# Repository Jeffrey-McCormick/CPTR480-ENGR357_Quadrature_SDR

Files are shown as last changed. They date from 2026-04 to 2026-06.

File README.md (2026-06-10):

# CPTR480 Quadrature SDR Hardware Documentation

This repository contains the KiCad schematics, PCB layouts, and Bills of Materials for the CPTR480 Quadrature Software Defined Radio (SDR) receiver board designed by Jeffrey McCormick and Daniel Mendoza for ENGR357 and CPTR480.

**Other contributors**: Riley Smith, Joshua Garbi

## System Architecture

The radio is a direct-conversion, quadrature-sampling receiver (commonly utilizing a Tayloe Detector topology) managed by a Raspberry Pi Pico. The RF front-end downconverts the incoming antenna signal directly to baseband I (In-phase) and Q (Quadrature) audio signals, which are digitized and processed by the RP2040 microcontroller. The board also includes other parts like rotary encoder, OLED display, SD card reader, and DAC for audio output for added functionality. The radio is designed work both on battery power as well as USB power through the Raspberry Pi Pico. The board is designed to be portable and hand-held. 

### Core Hardware Modules

1. **Microcontroller & Digital Core**
   - **Raspberry Pi Pico (RP2040)**: The brains of the SDR. Handles I2C UI/Hardware control, I2S digital audio streams, DSP, and SD card interfacing. The board will support both the original Raspberry Pi Pico board varients and the YD2040 from CPTR480. 

2. **RF Front-End & Mixing (Tayloe Detector)**
   - **SN74CBT3253CDBR**: Dual 1-of-4 FET Multiplexer/Demultiplexer. This high-speed analog switch acts as the quadrature mixer, sequentially sampling the incoming RF signal at the Local Oscillator frequency to produce differential baseband I and Q signals. A second SN74CBT was used for RF filter switching in the front-end.   
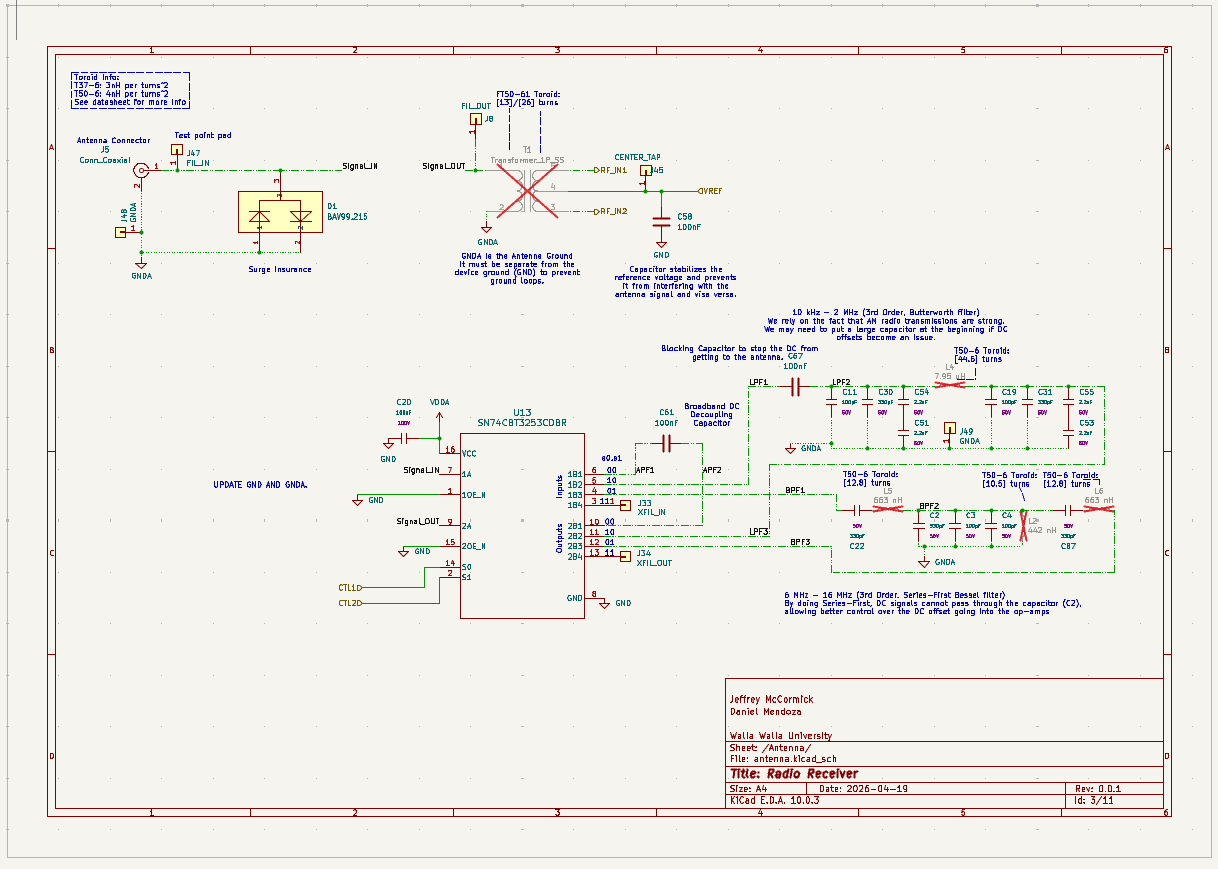
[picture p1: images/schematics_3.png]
SN74CBT3253CDBR
   
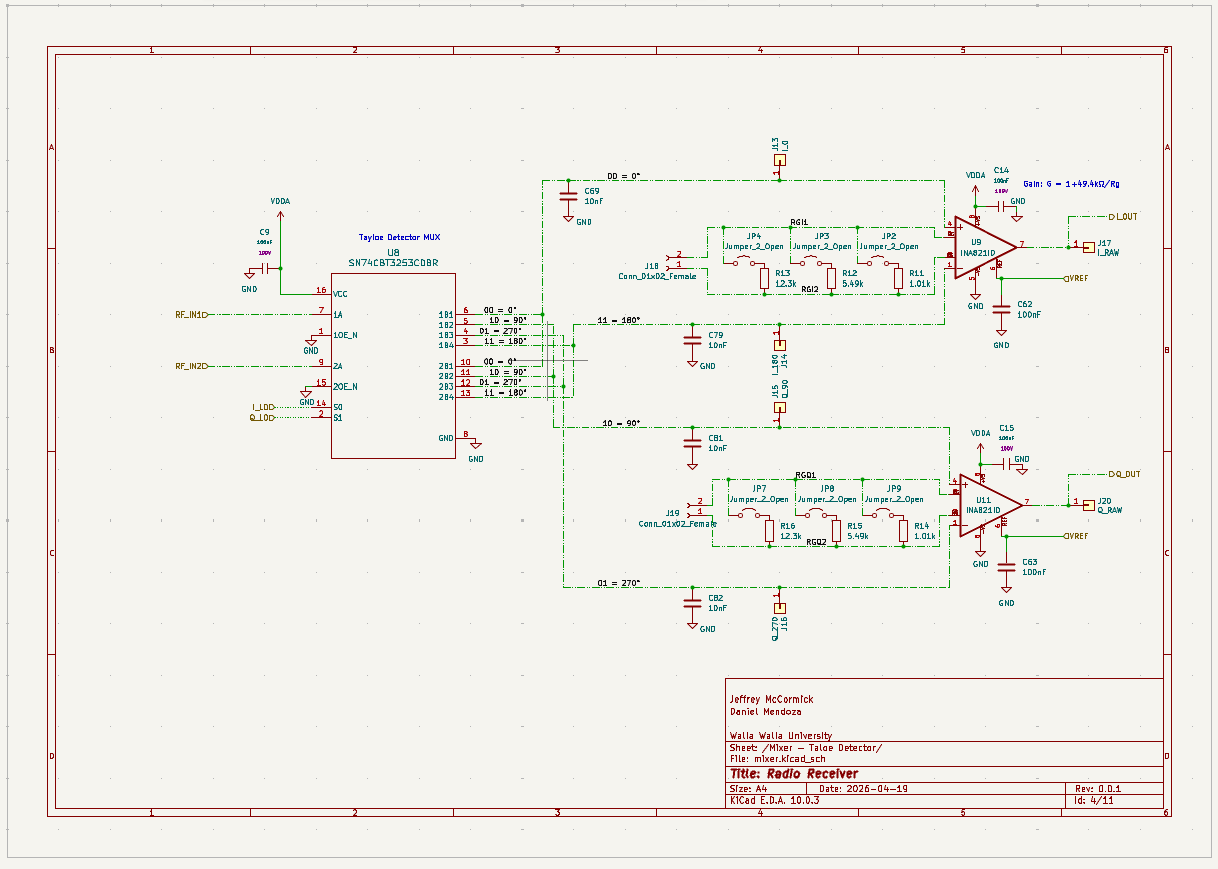
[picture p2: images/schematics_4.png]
Tayloe Detector
   
   - **SN74AC74DR**: Dual D-Type Positive-Edge-Triggered Flip-Flop, typically used to accurately divide the synthesized clock to drive the Tayloe detector switches with precise 90-degree phase offsets.
   Johnson Counter
   
3. **Clock Generation**
   - **Si5351A-B-GT**: I2C-programmable ANY-frequency CMOS clock generator. Driven by a high-precision **24.576 MHz TCXO** (ASTX-H11) for ultra-low drift, it synthesizes the Local Oscillator (LO) frequencies. For quadrature mixing, it is configured to output signals at 4x the target listen frequency.
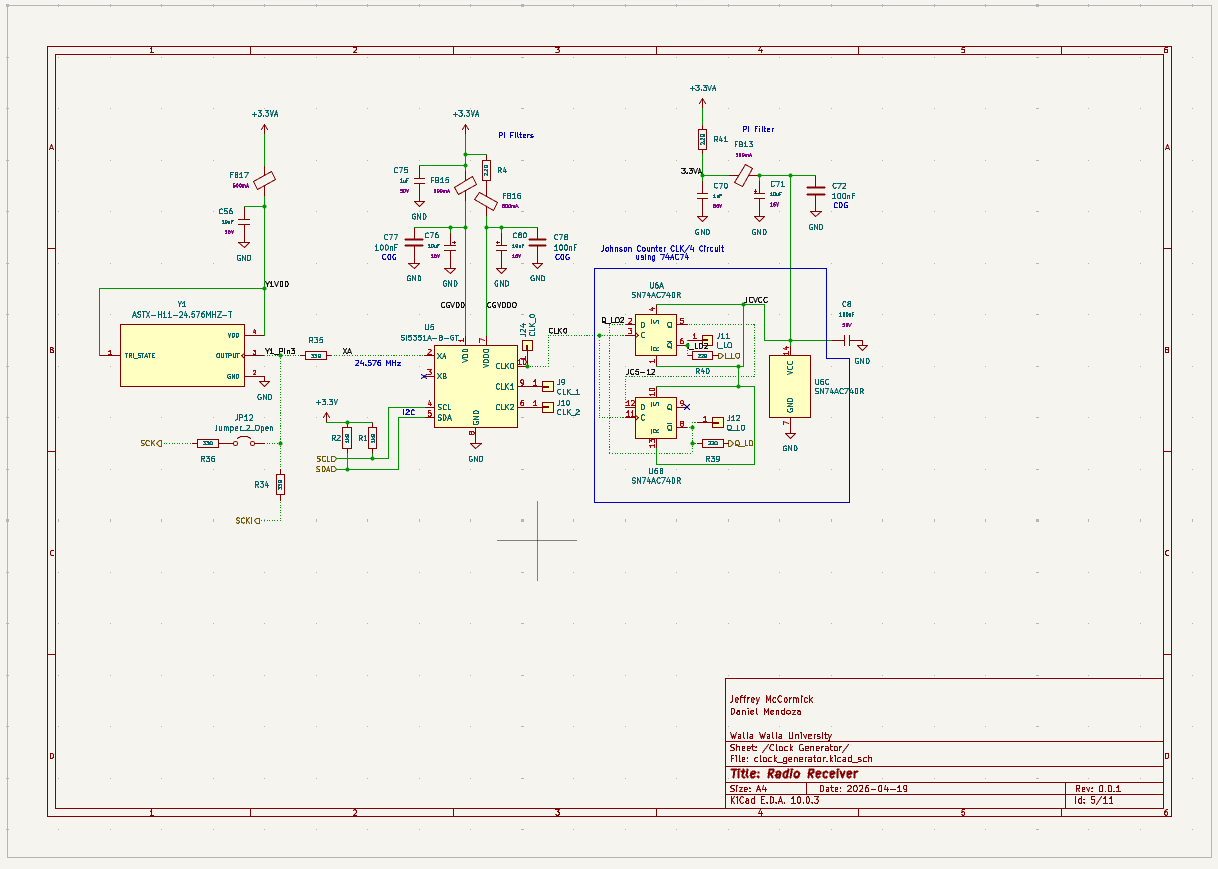
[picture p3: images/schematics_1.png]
Si5351A-B-GT
   

4. **Baseband Amplification**
   - **INA821ID**: High-precision instrumentation amplifiers used to convert the differential outputs of the Tayloe mixer to single-ended signals and apply initial low-noise gain.
   - **OPA1612AxD**: Dual SoundPlus™ high-performance bipolar-input audio operational amplifiers for active low-pass filtering and final baseband gain stages.

5. **Data Converters (Audio/Baseband)**
   - **PCM1808PWR**: 24-bit, 96-kHz Stereo ADC. Digitizes the analog I and Q baseband signals and sends them to the Pico over I2S.
   - **PCM5102A**: 32-bit, 384-kHz Stereo DAC with integrated PLL. Converts the final DSP-processed audio or playback audio from the Pico back to analog for the headphone output.
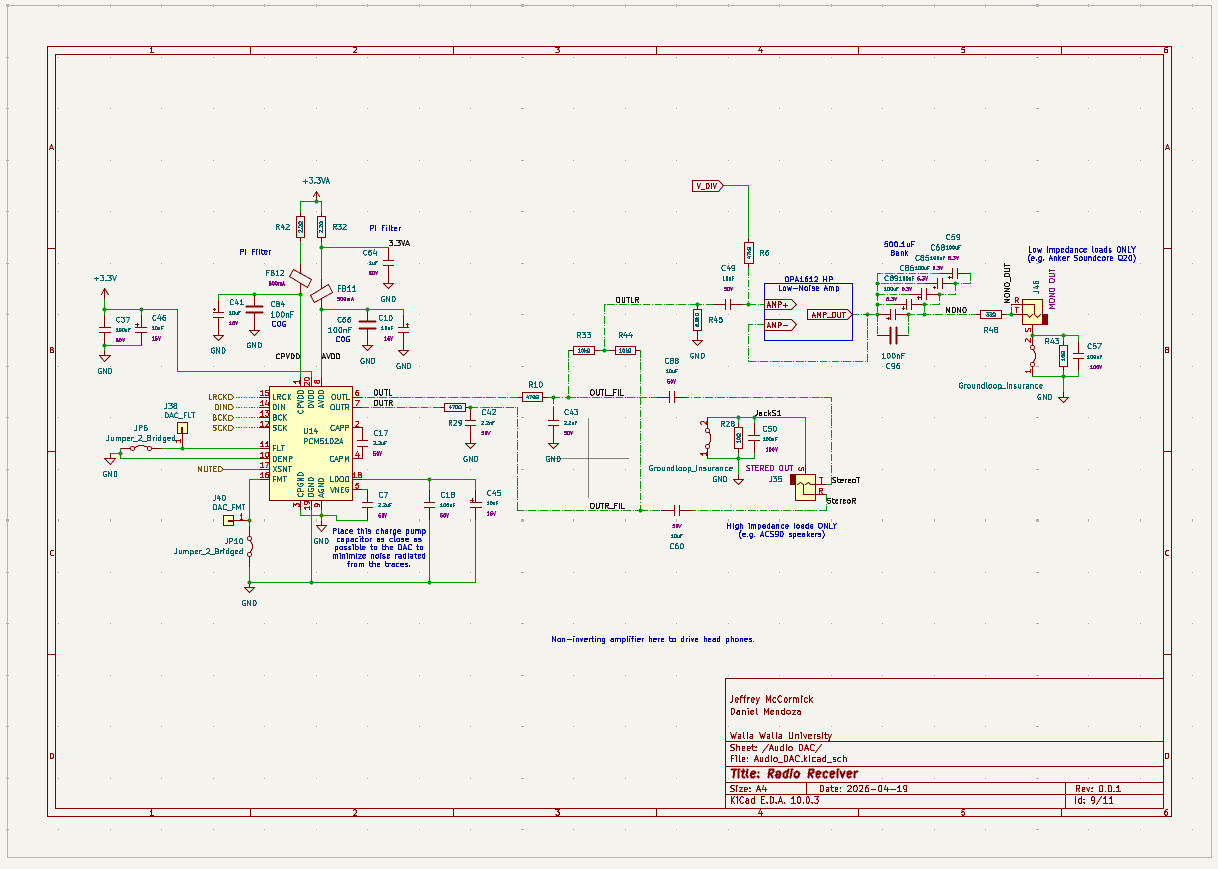
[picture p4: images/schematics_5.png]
DAC
   

6. **User Interface**
   - **0.96" OLED Display**: 128x64 pixels, I2C interface.
   - **Rotary Encoder (Alps EC11)**: Includes a push-button switch for frequency tuning and menu navigation.
   - **Tactile Button**: For additional UI control inputs.

7. **Power Management**
   - **TPS7A2045PDQN**: 4.5V Ultra-Low-Noise LDO regulator for sensitive analog components.
   - **TPS72733DSER**: 3.3V Low-Dropout regulator for clean digital/mixed-signal voltage rails.
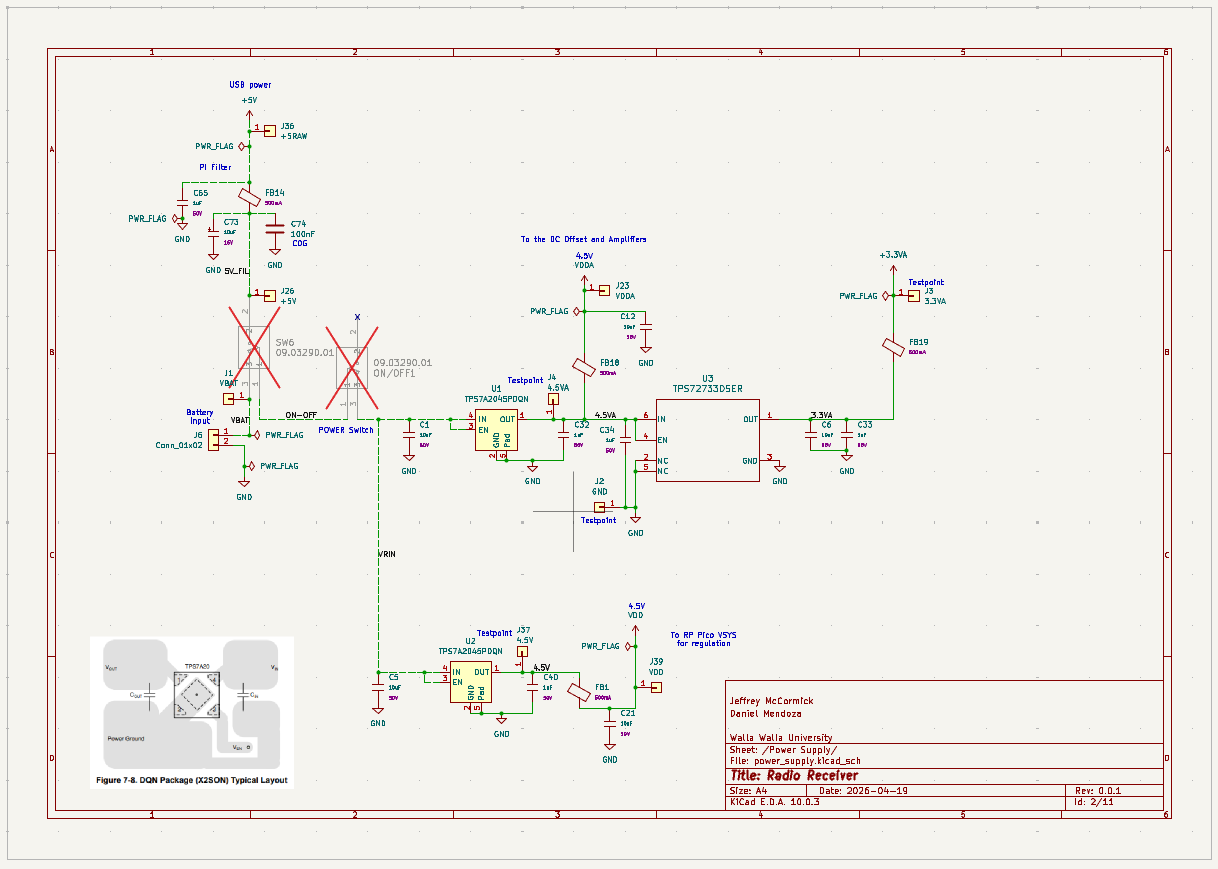
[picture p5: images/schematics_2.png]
Power Management
   

8. **Connectivity**
   - **BNC Connector (Amphenol)**: Main RF antenna input.
   - **3.5mm Audio Jacks (CUI SJ-3523-SMT)**: For SDR audio output and DAC direct output.
   - **MicroSD Card Slot**: Connected via SPI for playing WAV files or potentially recording IQ streams.

## KiCad Project Structure

The hardware source files are located in the `Radio_Receiver_McCormick_Mendoza` directory. The schematic is built hierarchically:

- **`Radio_Receiver_McCormick_Mendoza.kicad_sch`**: The top-level schematic tying all functional blocks together.
- **`antenna.kicad_sch` / `low_pass_filter.kicad_sch`**: Front-end filtering blocks.
- **`mixer.kicad_sch`**: The Tayloe detector and RF switching core.
- **`clock_generator.kicad_sch`**: Si5351 synthesizer and TCXO.
- **`ADC-24bit.kicad_sch` / `Audio_DAC.kicad_sch`**: Data converter sub-sheets.
- **`raspberry_pi_pico.kicad_sch`**: MCU pinning and decoupling.
- **`power_supply.kicad_sch`**: LDOs and power distribution network.
- **`Display.kicad_sch` / `Angle_Encoder.kicad_sch`**: UI peripherals.

### PCB Images
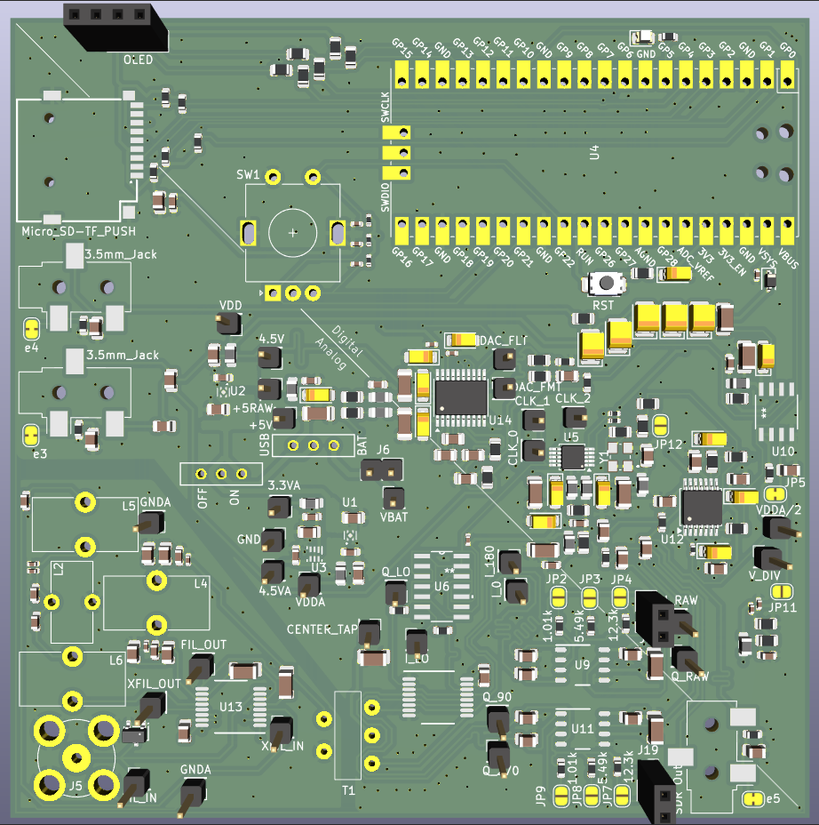
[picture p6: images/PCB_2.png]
Front of Board

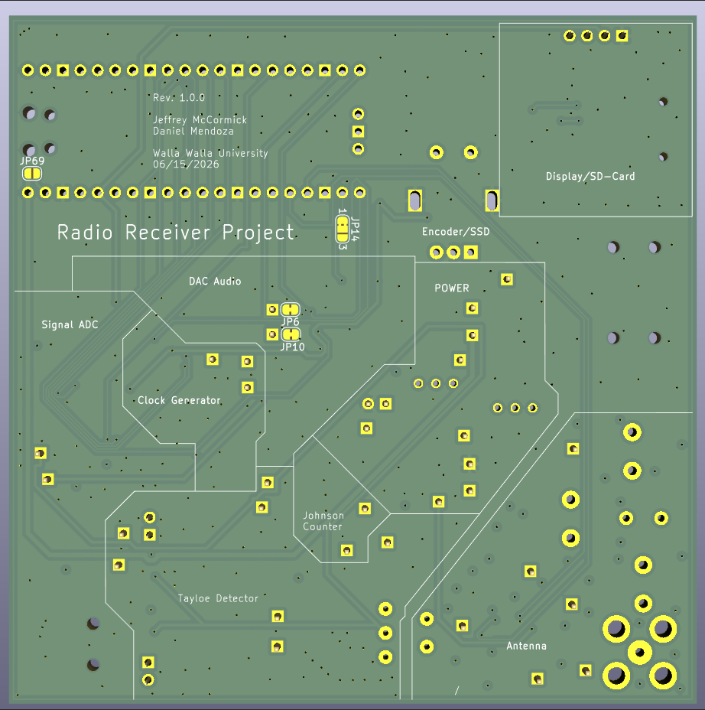
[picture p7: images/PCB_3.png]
Back of Board

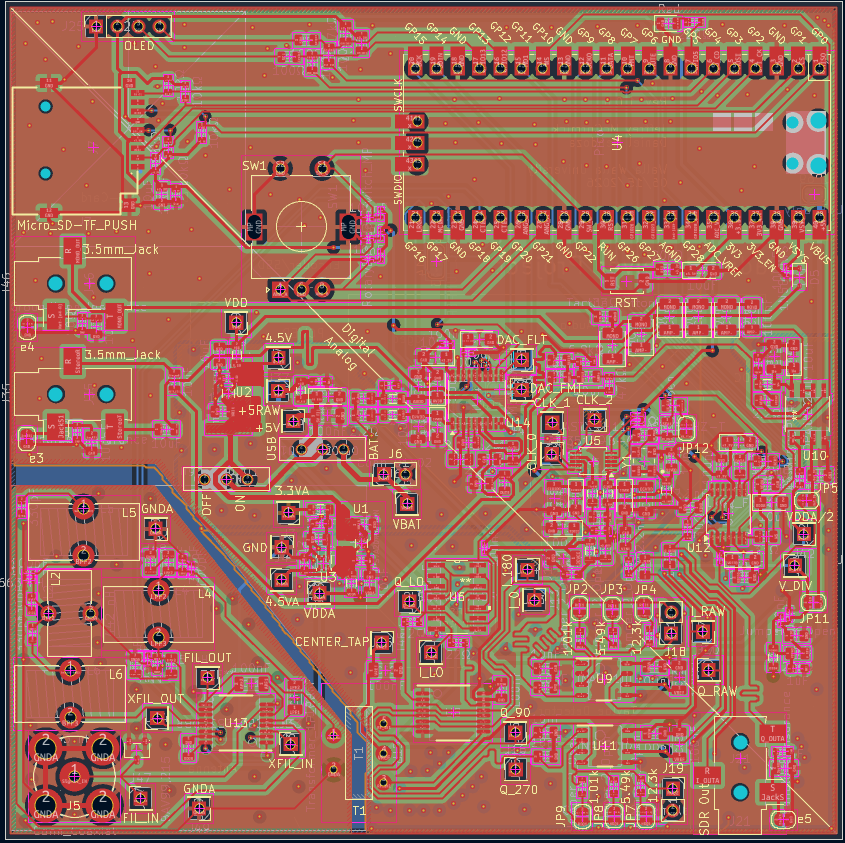
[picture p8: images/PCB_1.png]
PCB


### Bill of Materials (BOM)

The complete component list, including LCSC part numbers for JLCPCB assembly, can be found in `Radio_Receiver_McCormick_Mendoza.csv`.

## Bring-up and Testing Order

Standalone scripts used during hardware validation. Each can be uploaded and run independently on the board.

| Component | File | Function | Pass/Fail |
|---|---|---|---|
| LED | `Bringup/led_blink.py` | Blinks GPIO5 to confirm basic GPIO and upload toolchain | &check; |
| I2C bus | `Bringup/i2c_scan.py` | Scans I2C0 (SDA=12, SCL=13); expects Si5351 at `0x60`, OLED at `0x3C` | &check; |
| OLED display | `Bringup/oled_test.py` | Full exercise suite for the SSD1306 (text, lines, animation, contrast, power cycle) via `ssd1306.py` | &check; |
| Rotary encoder + button | `Bringup/rotary_encoder.py` | `QuadratureEncoder` (detent counting on GPIO 20/21) and `ButtonHandler` (debounced click + long-press on GPIO 22) | &check; |
| Si5351 clock | `Bringup/si5351_test.py` | Register R/W test, PLL lock check, 10.24 MHz quadrature setup, frequency sweep with integer-divider validation | &check; |
| Filter MUX | `Bringup/filter_mux_control.py` | Drives CTL1 (GPIO19) and CTL2 (GPIO18) to select one of four analog filter paths | &check; |
| Si5351 driver | `Bringup/Load_files/si5351.py` | I2C driver: PLL/multiplier config, per-clock dividers, phase offset, output enable | &check; |
| OLED driver | `Bringup/Load_files/ssd1306.py` | Standard MicroPython SSD1306 I2C framebuffer driver | &check; |
| DAC | `Bringup/dac.py` | I2S driver: Configure DAC for stereo or mono playback at 44.1 kHz | &check; |
| ADC | `Bringup/adc.py` | I2S driver: Configure ADC for 16-bit stereo sampling | &cross; |
|  ADC Integration | `Bringup/adc_test.py` | Full duplex loopback test: DAC outputs a sine wave, ADC reads it back, and an LED toggles based on amplitude | &cross; |

**`si5351_test.py` details:** Configures PLLA with N=25 (VCO = 24.576 MHz × 25 = 614.4 MHz), sets CLK0/1/2 dividers, and applies phase offsets of 0°, 90°, and 180° via `set_phase()`. The `is_integer_divider()` helper ensures only frequencies that divide the VCO evenly are programmed during the sweep.

**`rotary_encoder.py` details:** Encoder uses IRQ-driven quadrature decoding with detent aggregation (`ppr` parameter). `ButtonHandler` distinguishes short click (on release before 600 ms) from long press (held ≥ 600 ms); the main app uses long press for "back" navigation.
### Images
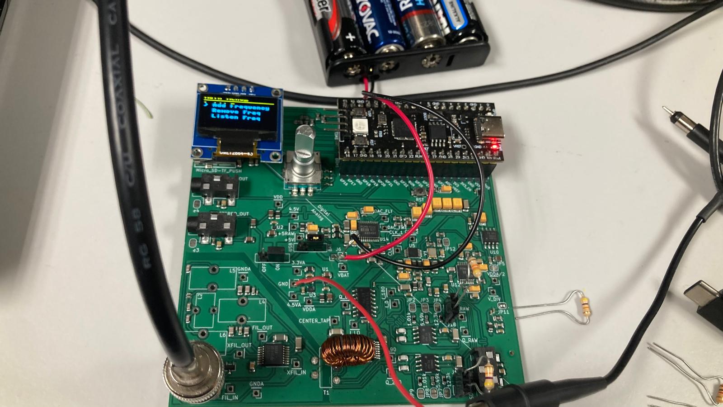
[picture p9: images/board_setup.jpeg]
Board Bring-UP


## Results

Base Goals

- [x]  Minimum Discernable signal less than 1uV
  - Achieved 1mV
- [ ]  Switching between AM and HF bands
  - Only tested for AM band. 
- [x]  Intuitive interface
  - Got it. See /Software 
- [x]  Portability
   - Battery power works well. Antenna and Board grounds have to be tied together for portable antenna grounding
- [x]  Dual power mode (battery and usb)
   - Got it!! Both work as intended.

 Reach Goals:

- [x]  Low noise (-60dB)
  - Achieved -90dB
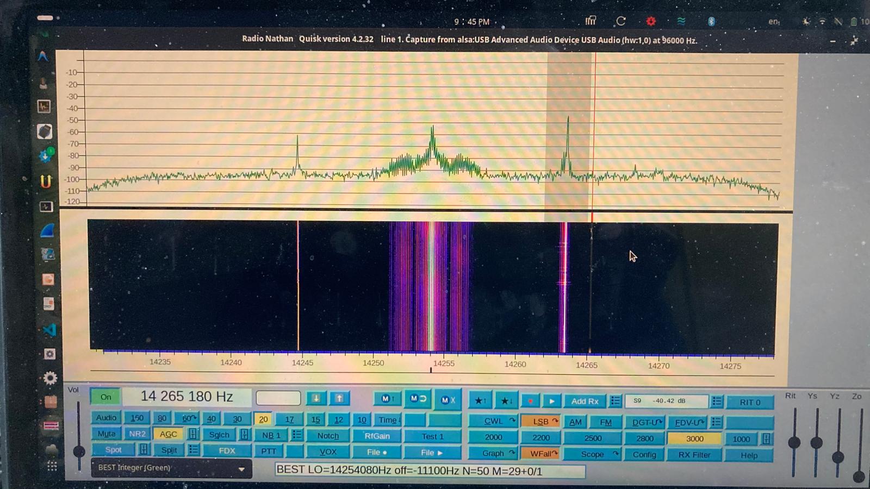
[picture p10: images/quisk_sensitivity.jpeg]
Quisk
  
- [/]  High Image Rejection (-20dB)
- Achieved -15dB to -25dB depending on individual resistor pairs. 
- [ ]  Can record radio signals
   - Unable to test 

### Images
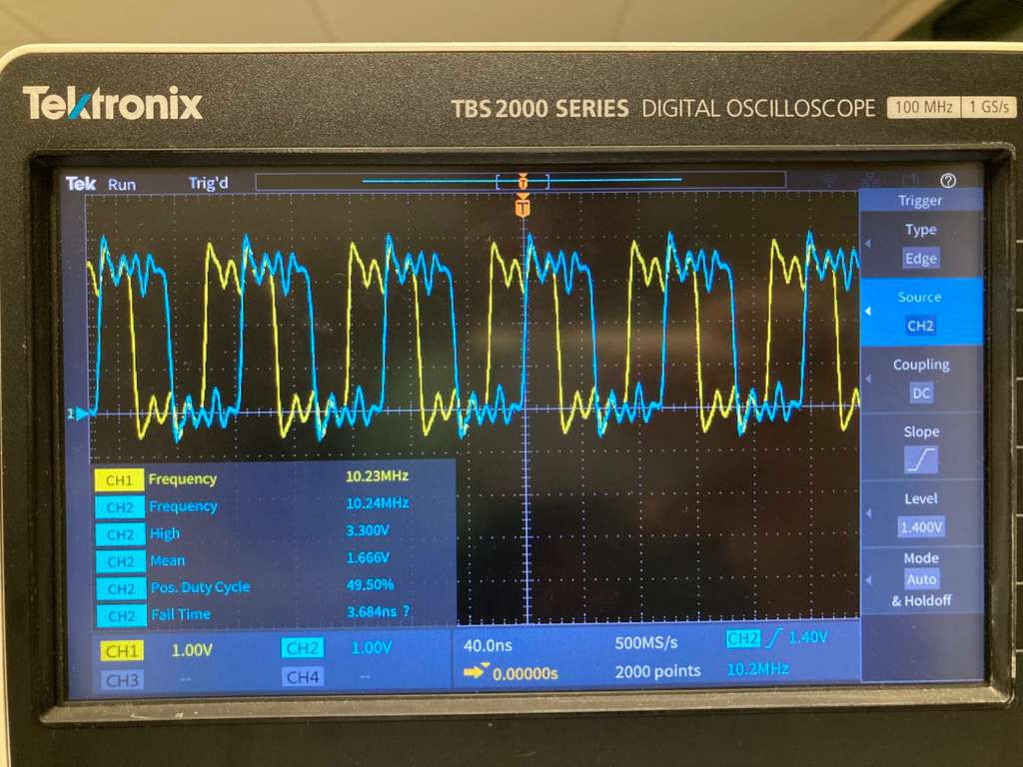
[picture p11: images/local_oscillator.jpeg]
Local Oscillator


## Future Work

- [ ] Input I and Q signls into pico via ADC 
   - ADC verification 
- [ ] Tracelength matching for Q_LO and I_LO
- [ ] Manufacture optional LP and BP Filters
- [ ] RF signal processing software

### Optional
- [ ] Adding option for lower gain in Intrumentation Amplifier.

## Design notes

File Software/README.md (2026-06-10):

# Overview

MicroPython firmware for the CPTR480 Quadrature SDR board (RP2040 / Pico-class). The software drives the Si5351 clock generator for quadrature LO signals, an SSD1306 OLED and rotary encoder for the user interface, an analog filter MUX, and (separately) SD-card WAV playback through a PCM5102A DAC over I2S.

**Entry point:** `main.py` configures the Si5351, then launches the `SDRApp` menu.

**Typical pin map (shared across modules):**

| Signal | GPIO |
|---|---|
| I2C SDA | 12 |
| I2C SCL | 13 |
| Encoder A / B | 20 / 21 |
| Encoder button | 22 |
| DAC I2S BCK / WS / DATA | 15 / 16 / 14 |
| DAC mute (XSMT) | 6 |
| SD SPI CS / SCK / MOSI / MISO | 1 / 2 / 3 / 0 |
| Filter MUX CTL1 / CTL2 | 19 / 18 |

Library copies of `si5351.py` and `ssd1306.py` live in `Bringup/Load_files/` and are imported from there during bringup; production code expects them on the device root alongside the app modules.

---

## Drivers

### Bringup

Standalone scripts used during hardware validation. Each can be uploaded and run independently on the board.

| Component | File | Function | Pass/Fail |
|---|---|---|---|
| LED | `Bringup/led_blink.py` | Blinks GPIO5 to confirm basic GPIO and upload toolchain | — |
| I2C bus | `Bringup/i2c_scan.py` | Scans I2C0 (SDA=12, SCL=13); expects Si5351 at `0x60`, OLED at `0x3C` | — |
| OLED display | `Bringup/oled_test.py` | Full exercise suite for the SSD1306 (text, lines, animation, contrast, power cycle) via `ssd1306.py` | — |
| Rotary encoder + button | `Bringup/rotary_encoder.py` | `QuadratureEncoder` (detent counting on GPIO 20/21) and `ButtonHandler` (debounced click + long-press on GPIO 22) | — |
| Si5351 clock | `Bringup/si5351_test.py` | Register R/W test, PLL lock check, 10.24 MHz quadrature setup, frequency sweep with integer-divider validation | — |
| Filter MUX | `Bringup/filter_mux_control.py` | Drives CTL1 (GPIO19) and CTL2 (GPIO18) to select one of four analog filter paths | — |
| Si5351 driver | `Bringup/Load_files/si5351.py` | I2C driver: PLL/multiplier config, per-clock dividers, phase offset, output enable | — |
| OLED driver | `Bringup/Load_files/ssd1306.py` | Standard MicroPython SSD1306 I2C framebuffer driver | — |

**`si5351_test.py` details:** Configures PLLA with N=25 (VCO = 24.576 MHz × 25 = 614.4 MHz), sets CLK0/1/2 dividers, and applies phase offsets of 0°, 90°, and 180° via `set_phase()`. The `is_integer_divider()` helper ensures only frequencies that divide the VCO evenly are programmed during the sweep.

**`rotary_encoder.py` details:** Encoder uses IRQ-driven quadrature decoding with detent aggregation (`ppr` parameter). `ButtonHandler` distinguishes short click (on release before 600 ms) from long press (held ≥ 600 ms); the main app uses long press for "back" navigation.

---

### UI

The menu system is split between a legacy `Menu` renderer and a page-stack navigation layer.

| File | Role |
|---|---|
| `menu.py` | **`Menu`** — draws a scrollable option list on the 128×64 OLED. **`SDRApp`** — wires I2C/OLED, encoder, and button; owns the frequency list and `NavStack`; main event loop running cooperatively via `asyncio`. |
| `ui/page.py` | **`Page`** base class (`on_enter`, `on_exit`, `handle_input`, `draw`). **`NavStack`** — push/pop/replace for nested screens; root page cannot be popped. |
| `ui/menu_page.py` | **`MenuPage`** — builds a `Menu` from `MenuItem` definitions; click navigates to a child page or runs an action; optional back row. |
| `ui/freq_pages.py` | **`ValueEditorPage`** — encoder adjusts a numeric value in Hz; click saves. **`AddFreqPage`** — adds a frequency to the sorted `app.freqs` list. **`FreqListPage`** — lists saved frequencies for remove or listen actions. |
| `ui/music_pages.py` | **`MusicListPage`** — selectable list of WAV files from the SD card. **`PlaybackPage`** — playback controls (Play, Pause, Exit) for a track, interfacing with `PlaybackController`. |
| `ui/screen_mode_page.py` | **`ScreenModePage`** — placeholder page for displaying SD card photos (Coming Soon). |

**Navigation model:**

- Rotate encoder → move selection up/down.
- Short click → confirm / enter submenu.
- Long press → go back (when not on root menu).

**Main menu options (FrohnePod):**

1. **Radio** — enter submenu to Add, Remove, or Listen to SDR frequencies.
2. **Music Player** — browse `.wav` files on the SD card and enter the playback screen.
3. **Screen Mode** — enter submenu for screen viewing modes.

`main.py` calls `configure_si5351()` before starting the app, setting CLK0 to 1.42 MHz as the initial LO.

---

### Audio Stream

WAV playback from the SD card is handled cooperatively with `asyncio` (not a second RP2040 core). The design keeps the I2S feed non-blocking relative to other tasks by yielding whenever the hardware ring buffer is full.

| File | Role |
|---|---|
| `sd.py` | SPI mount helper (`mount_sd`) and `list_wav_files` for `.wav` files on `/sd`. |
| `sdcard.py` | Low-level SPI SD-card driver (`readblocks` / `writeblocks` for `os.mount`). Busy-poll read path tuned for streaming throughput. |
| `player/PlaybackController.py` | Async WAV streamer: mounts SD, opens PCM5102A via `DAC`, spawns `_stream_task` on `play()`. |

**`PlaybackController` flow:**

1. `initialize()` — mount SD, create `DAC` in non-blocking stereo mode (muted).
2. `play(filename)` — skip WAV header to PCM `data` chunk, start asyncio task.
3. `_stream_task` — reads chunks from the file, writes to I2S directly via non-blocking `write()`, and yields to the UI event loop via `asyncio.sleep_ms(10)` when the hardware ring buffer is full. Unmutes after two buffered chunks; on EOF waits 300 ms for the ring to drain before muting.
4. `pause()` / `resume()` / `stop()` — mute control and task cancellation with a generation counter so stale tasks cannot clobber state.

**Expected audio format:** 16-bit stereo PCM WAV at the DAC sample rate (default 44.1 kHz). Mono or other formats are not handled.

**Standalone usage:** `sd.py` can be run directly (`python sd.py` on-device) to play the first track found on the card.

Watch this lol

---

### DAC

`dac.py` wraps the RP2040 I2S peripheral for a PCM5102A DAC.

| Feature | Detail |
|---|---|
| Pins | BCK=15, WS=16, DATA=14, XSMT mute=6, MCLK=17 |
| Modes | Stereo (default) or mono via `set_stereo()` / `set_mono()` |
| Blocking vs non-blocking | `nonblocking=True` enables non-blocking writes and lets the `PlaybackController` cooperatively yield while the buffer is full |
| Mute | `mute()` / `unmute()` drive XSMT LOW/HIGH |
| Shutdown | `close()` — clears IRQ, mutes, deinits I2S |

The DAC requires an external Master Clock (`MCLK`). `dac.py` sets up a PWM signal on Pin 17 at `256 * sample_rate` to satisfy the PCM5102A's MCLK requirement.

The `__main__` block generates a 440 Hz sine wave for a quick hardware smoke test.

---

## Outcome

### Problems

- **Listen Freq is a stub** — selecting a frequency in `FreqListPage` only prints to the serial console; it does not yet call `Si5351` to retune the LO or select a filter MUX channel.
- **Si5351 config split** — clock setup lives in `main.py` (`configure_si5351`) while the UI frequency list is separate; there is no shared tuning API yet.
- **Module path** — `menu.py` falls back to `Bringup/` on import error; deployed firmware should copy `si5351.py`, `ssd1306.py`, and `rotary_encoder.py` to the device root to avoid path hacks.
- **Encoder debug prints** — `QuadratureEncoder.on_change` still prints on every edge; noisy during normal UI use.
- **WAV assumptions** — playback expects 16-bit stereo PCM; no sample-rate negotiation or resampling.
- **Filter MUX unused in app** — `filter_mux_control.py` is bringup-only; channel selection is not tied to frequency or listen mode.

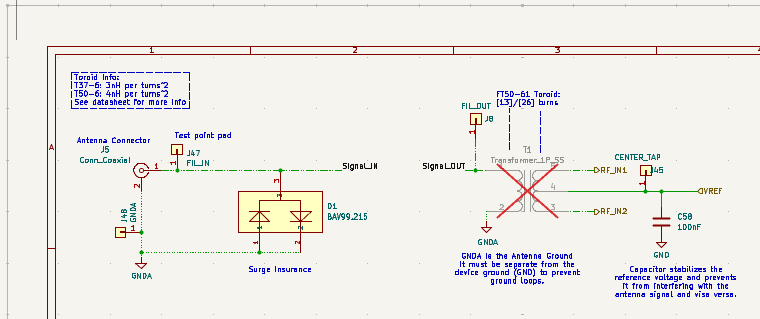
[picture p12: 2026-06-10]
images/schematics_6.png

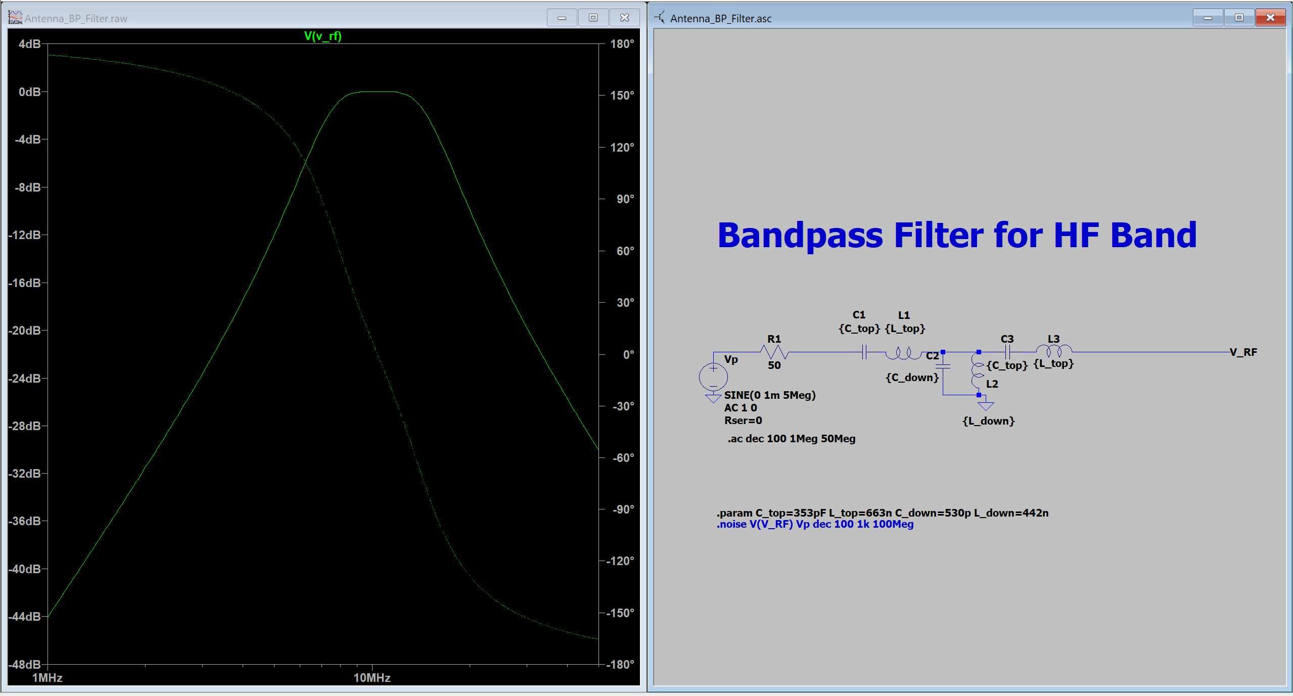
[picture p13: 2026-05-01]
Pictures/BandpassFilterSimulations.png

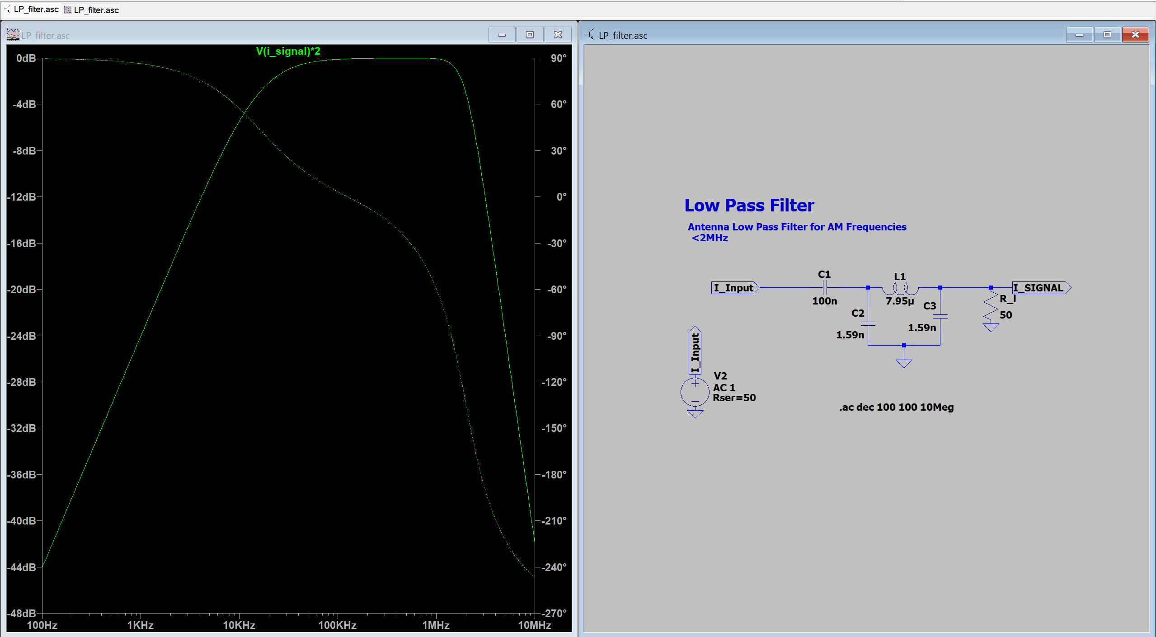
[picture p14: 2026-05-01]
Pictures/LowpassFilterSimulations.png

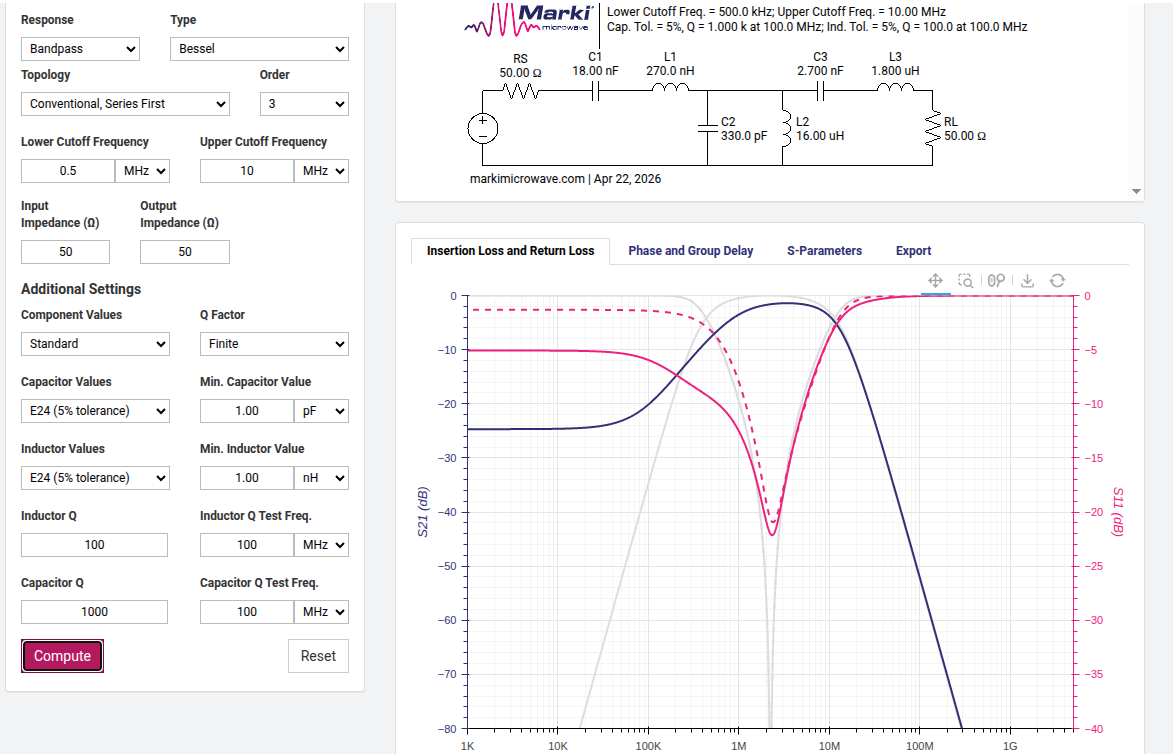
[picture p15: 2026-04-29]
Pictures/MarkiMicrowave_BPF_3rdBessel_Calc.png

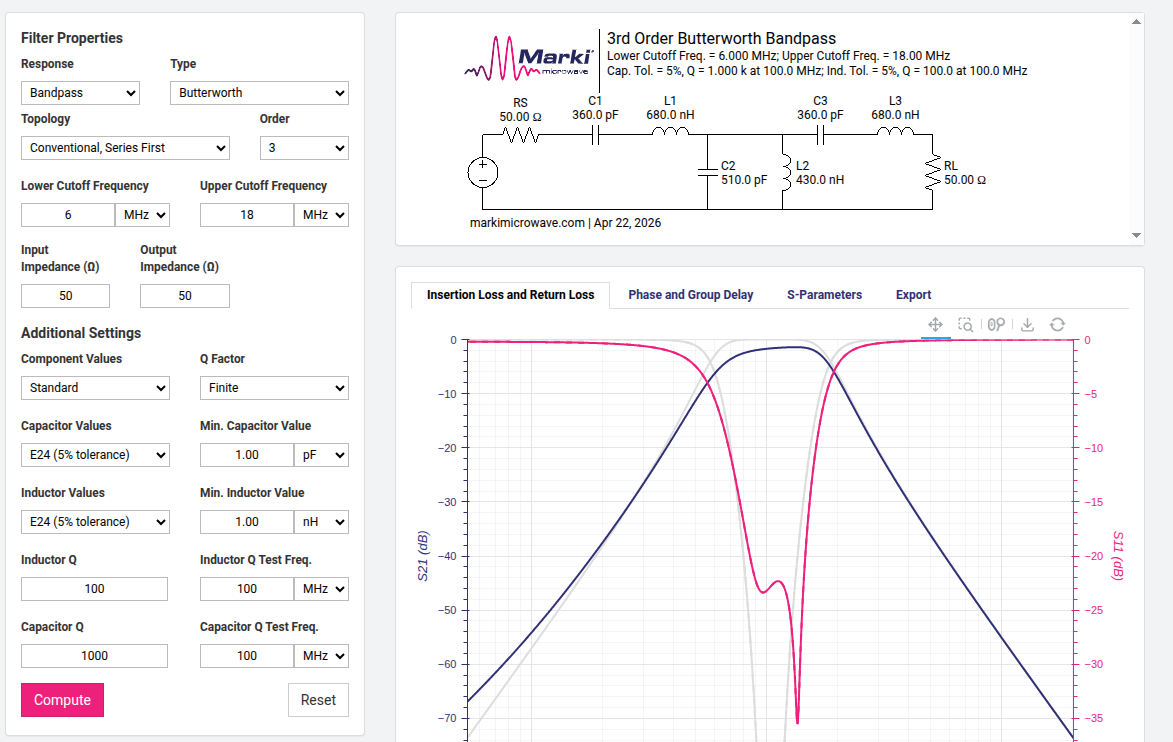
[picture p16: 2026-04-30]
Pictures/MarkiMicrowave_LPF_3rdButterworth_Calc1.png

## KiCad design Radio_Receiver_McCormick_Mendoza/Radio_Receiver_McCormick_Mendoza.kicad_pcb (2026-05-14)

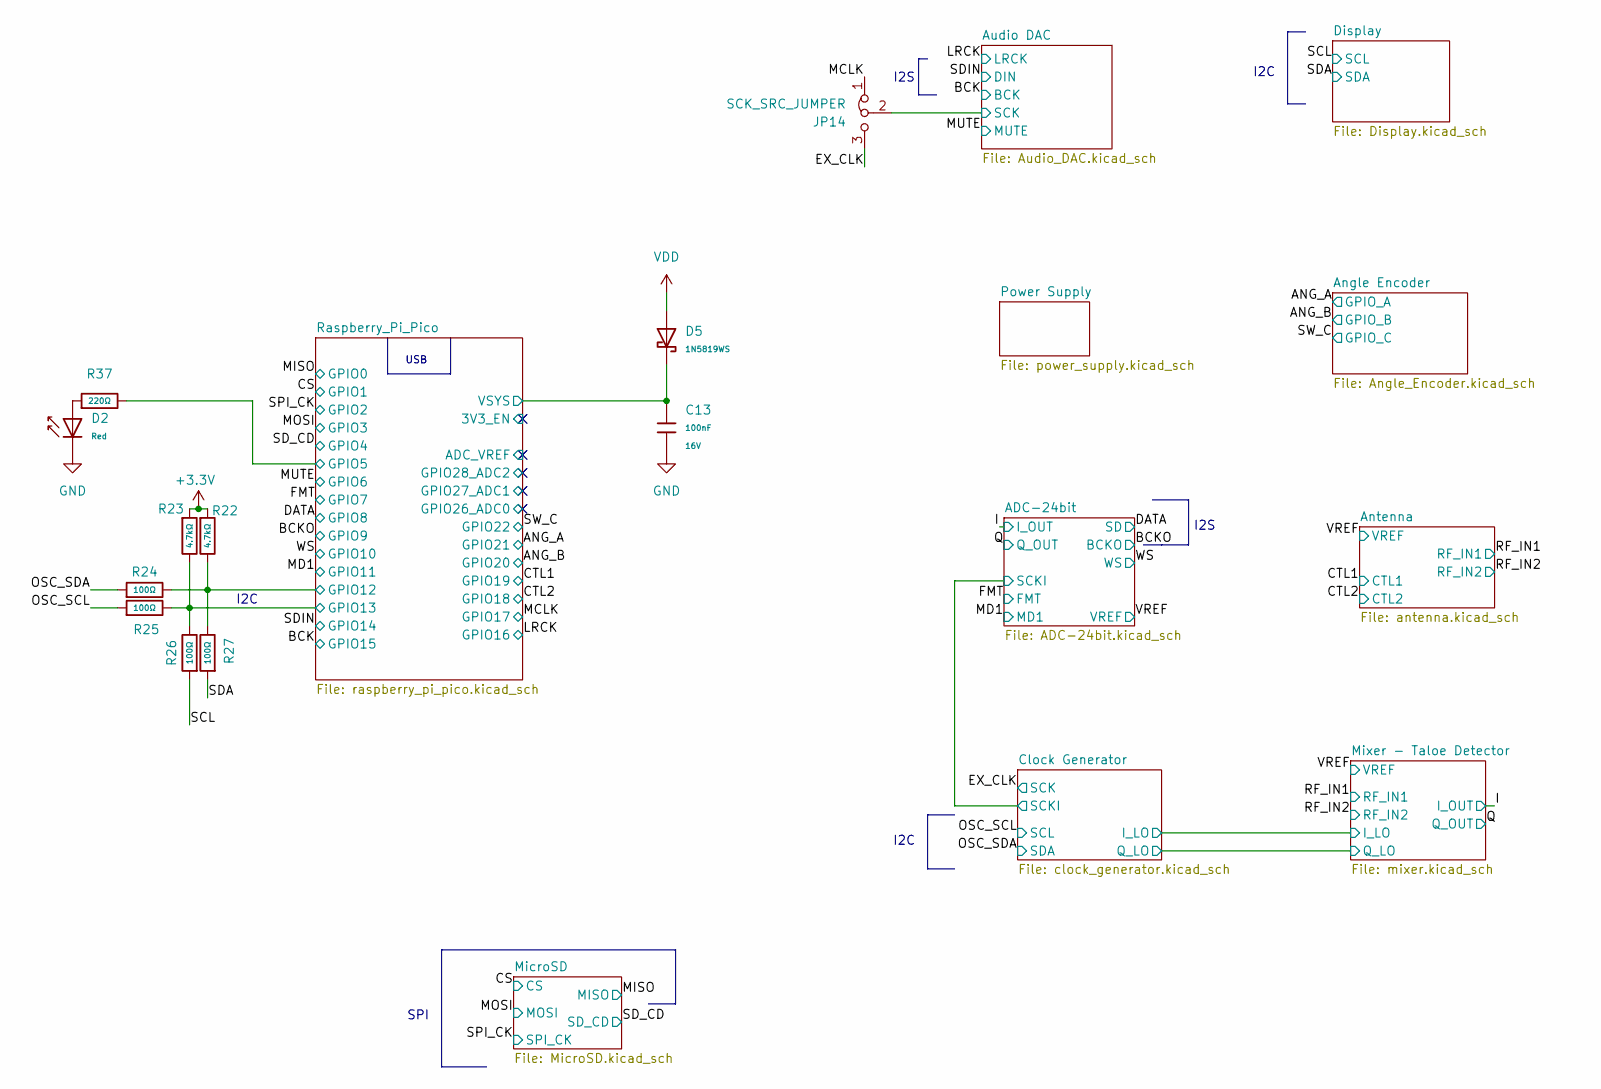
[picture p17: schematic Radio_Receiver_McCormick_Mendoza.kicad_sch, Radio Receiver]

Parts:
C13: 100nF; C_0402; Voltage Rated 16V; Tolerance ±10%; Part CL05B104KO5NNNC; LCSC C1525
D2: Red; D_0805; Forward Voltage (VF) 1.6V~2.6V; Part NCD0805R1; LCSC C84256
D5: 1N5819WS; D_SOD-323; Forward Voltage (Vf@If) 600mV@1A; Reverse Voltage (Vr) 40V; Part 1N5819WS; LCSC C191023
JP14: SCK_SRC_JUMPER; SolderJumper-3_P1.3mm_Bridged2Bar12_RoundedPad1.0x1.5mm_Num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
R22, R23: 4.7kΩ; R_0805; Overload Voltage (Max) 150V; Tolerance ±1%; Part 0805W8F4701T5E; LCSC C17673
R24, R25, R26, R27: 100Ω; R_0805; Overload Voltage (Max) 150V; Tolerance ±1%; Part 0805W8F1000T5E; LCSC C17408
R37: 220Ω; R_0603; Overload Voltage (Max) 75V; Tolerance ±1%; Part 0603WAF2200T5E; LCSC C22962

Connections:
+3.3V: R22.1, R23.1; also elsewhere on the board
/Audio DAC/SCK: JP14.2 (C); also elsewhere on the board
/EX_CLK: JP14.3 (B); also elsewhere on the board
/MCLK: JP14.1 (A); also elsewhere on the board
/OSC_SCL: R25.1; also elsewhere on the board
/OSC_SDA: R24.1; also elsewhere on the board
/Raspberry_Pi_Pico/GPIO5: R37.2; also elsewhere on the board
/Raspberry_Pi_Pico/GPIO12: R22.2, R24.2, R27.2; also elsewhere on the board
/Raspberry_Pi_Pico/GPIO13: R23.2, R25.2, R26.2; also elsewhere on the board
/Raspberry_Pi_Pico/VSYS: C13.1, D5.1; also elsewhere on the board
/SCL: R26.1; also elsewhere on the board
/SDA: R27.1; also elsewhere on the board
GND: C13.2, D2.1; also elsewhere on the board
unnamed: D2.2, R37.1
VDD: D5.2; also elsewhere on the board

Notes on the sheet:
I2S
USB
I2C
SPI

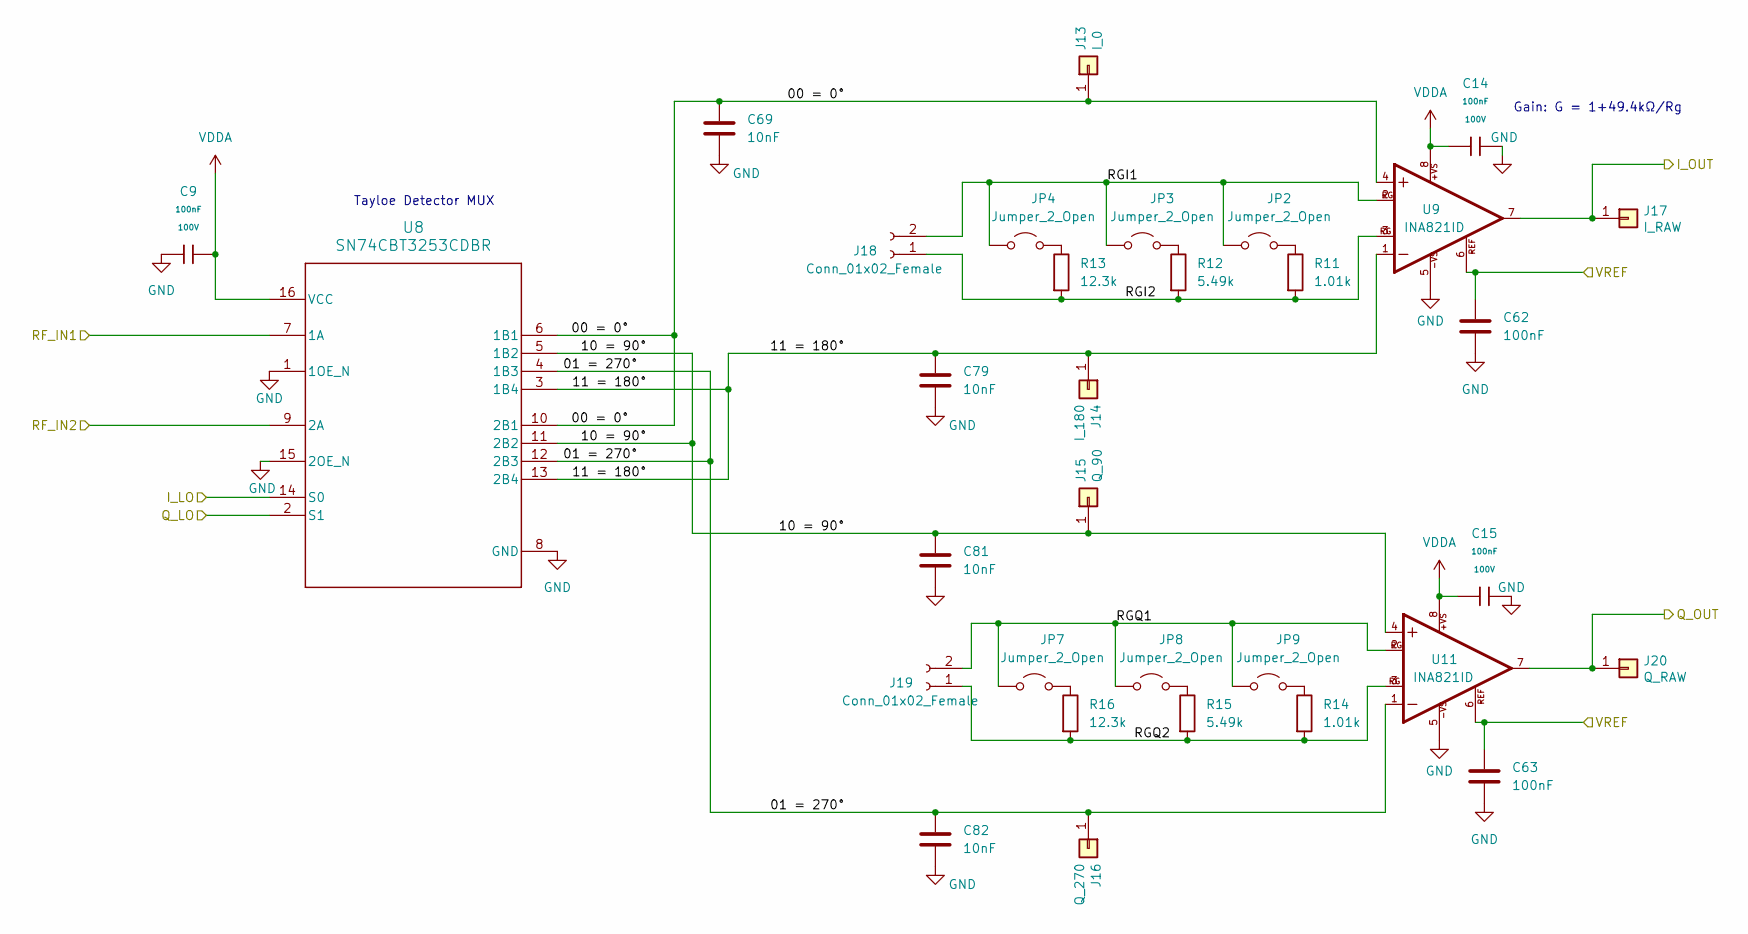
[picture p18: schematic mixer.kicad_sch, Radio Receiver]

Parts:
C9, C14, C15: 100nF; C_0805; Voltage Rated 100V; Tolerance ±10%; Part CL21B104KCFNNNE; LCSC C28233
C62, C63: 100nF; C_1206; LCSC C52147198
C69, C79, C81, C82: 10nF; C_0805; LCSC C49326666
J13: I_0; PinHeader_1x01_P2.54mm_Vertical
J14: I_180; PinHeader_1x01_P2.54mm_Vertical
J15: Q_90; PinHeader_1x01_P2.54mm_Vertical
J16: Q_270; PinHeader_1x01_P2.54mm_Vertical
J17: I_RAW; PinHeader_1x01_P2.54mm_Vertical
J18, J19: Conn_01x02_Female; PinSocket_1x02_P2.54mm_Vertical
J20: Q_RAW; PinHeader_1x01_P2.54mm_Vertical
JP2, JP3, JP4, JP7, JP8, JP9: Jumper_2_Open; SolderJumper-2_P1.3mm_Open_RoundedPad1.0x1.5mm
R11, R14: 1.01k; R_0603; LCSC C861188
R12, R15: 5.49k; R_0603; LCSC C861486
R13, R16: 12.3k; R_0603; LCSC C861101
U8: SN74CBT3253CDBR; DB0016A_N; LCSC C2674583
U9, U11: INA821ID; D0008A_N; LCSC C2060822

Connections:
/Clock Generator/I_LO: U8.14 (S0); also elsewhere on the board
/Clock Generator/Q_LO: U8.2 (S1); also elsewhere on the board
/I: J17.1 (Pin_1_1), U9.7 (OUT); also elsewhere on the board
/Mixer - Taloe Detector/00 = 0°: C69.2, J13.1 (Pin_1_1), U8.6 (1B1), U8.10 (2B1), U9.4 (+IN)
/Mixer - Taloe Detector/01 = 270°: C82.2, J16.1 (Pin_1_1), U8.4 (1B3), U8.12 (2B3), U11.1 (-IN)
/Mixer - Taloe Detector/10 = 90°: C81.2, J15.1 (Pin_1_1), U8.5 (1B2), U8.11 (2B2), U11.4 (+IN)
/Mixer - Taloe Detector/11 = 180°: C79.2, J14.1 (Pin_1_1), U8.3 (1B4), U8.13 (2B4), U9.1 (-IN)
/Mixer - Taloe Detector/RGI1: J18.2, JP2.1 (A), JP3.1 (A), JP4.1 (A), U9.2 (RG)
/Mixer - Taloe Detector/RGI2: J18.1, R11.2, R12.2, R13.2, U9.3 (RG1)
/Mixer - Taloe Detector/RGQ1: J19.2, JP7.1 (A), JP8.1 (A), JP9.1 (A), U11.2 (RG)
/Mixer - Taloe Detector/RGQ2: J19.1, R14.2, R15.2, R16.2, U11.3 (RG1)
/Q: J20.1 (Pin_1_1), U11.7 (OUT); also elsewhere on the board
/RF_IN1: U8.7 (1A); also elsewhere on the board
/RF_IN2: U8.9 (2A); also elsewhere on the board
/VREF: C62.1, C63.1, U9.6 (REF), U11.6 (REF); also elsewhere on the board
GND: C9.1, C14.2, C15.2, C62.2, C63.2, C69.1, C79.1, C81.1, C82.1, U8.1 (1OE_N), U8.8 (GND), U8.15 (2OE_N), U9.5 (-VS), U11.5 (-VS); also elsewhere on the board
unnamed: JP2.2 (B), R11.1
unnamed: JP3.2 (B), R12.1
unnamed: JP4.2 (B), R13.1
unnamed: JP7.2 (B), R16.1
unnamed: JP8.2 (B), R15.1
unnamed: JP9.2 (B), R14.1
VDDA: C9.2, C14.1, C15.1, U8.16 (VCC), U9.8 (+VS), U11.8 (+VS); also elsewhere on the board

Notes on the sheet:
Tayloe Detector MUX
Gain: G = 1+49.4kΩ/Rg

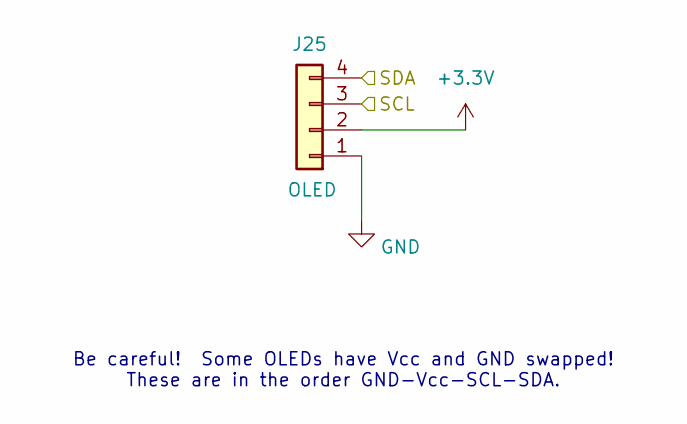
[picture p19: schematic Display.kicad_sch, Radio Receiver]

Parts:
J25: OLED; PinSocket_1x04_P2.54mm_Vertical; LCSC C2718488

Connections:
+3.3V: J25.2; also elsewhere on the board
/SCL: J25.3; also elsewhere on the board
/SDA: J25.4; also elsewhere on the board
GND: J25.1; also elsewhere on the board

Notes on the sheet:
Be careful! Some OLEDs have Vcc and GND swapped! These are in the order GND-Vcc-SCL-SDA.

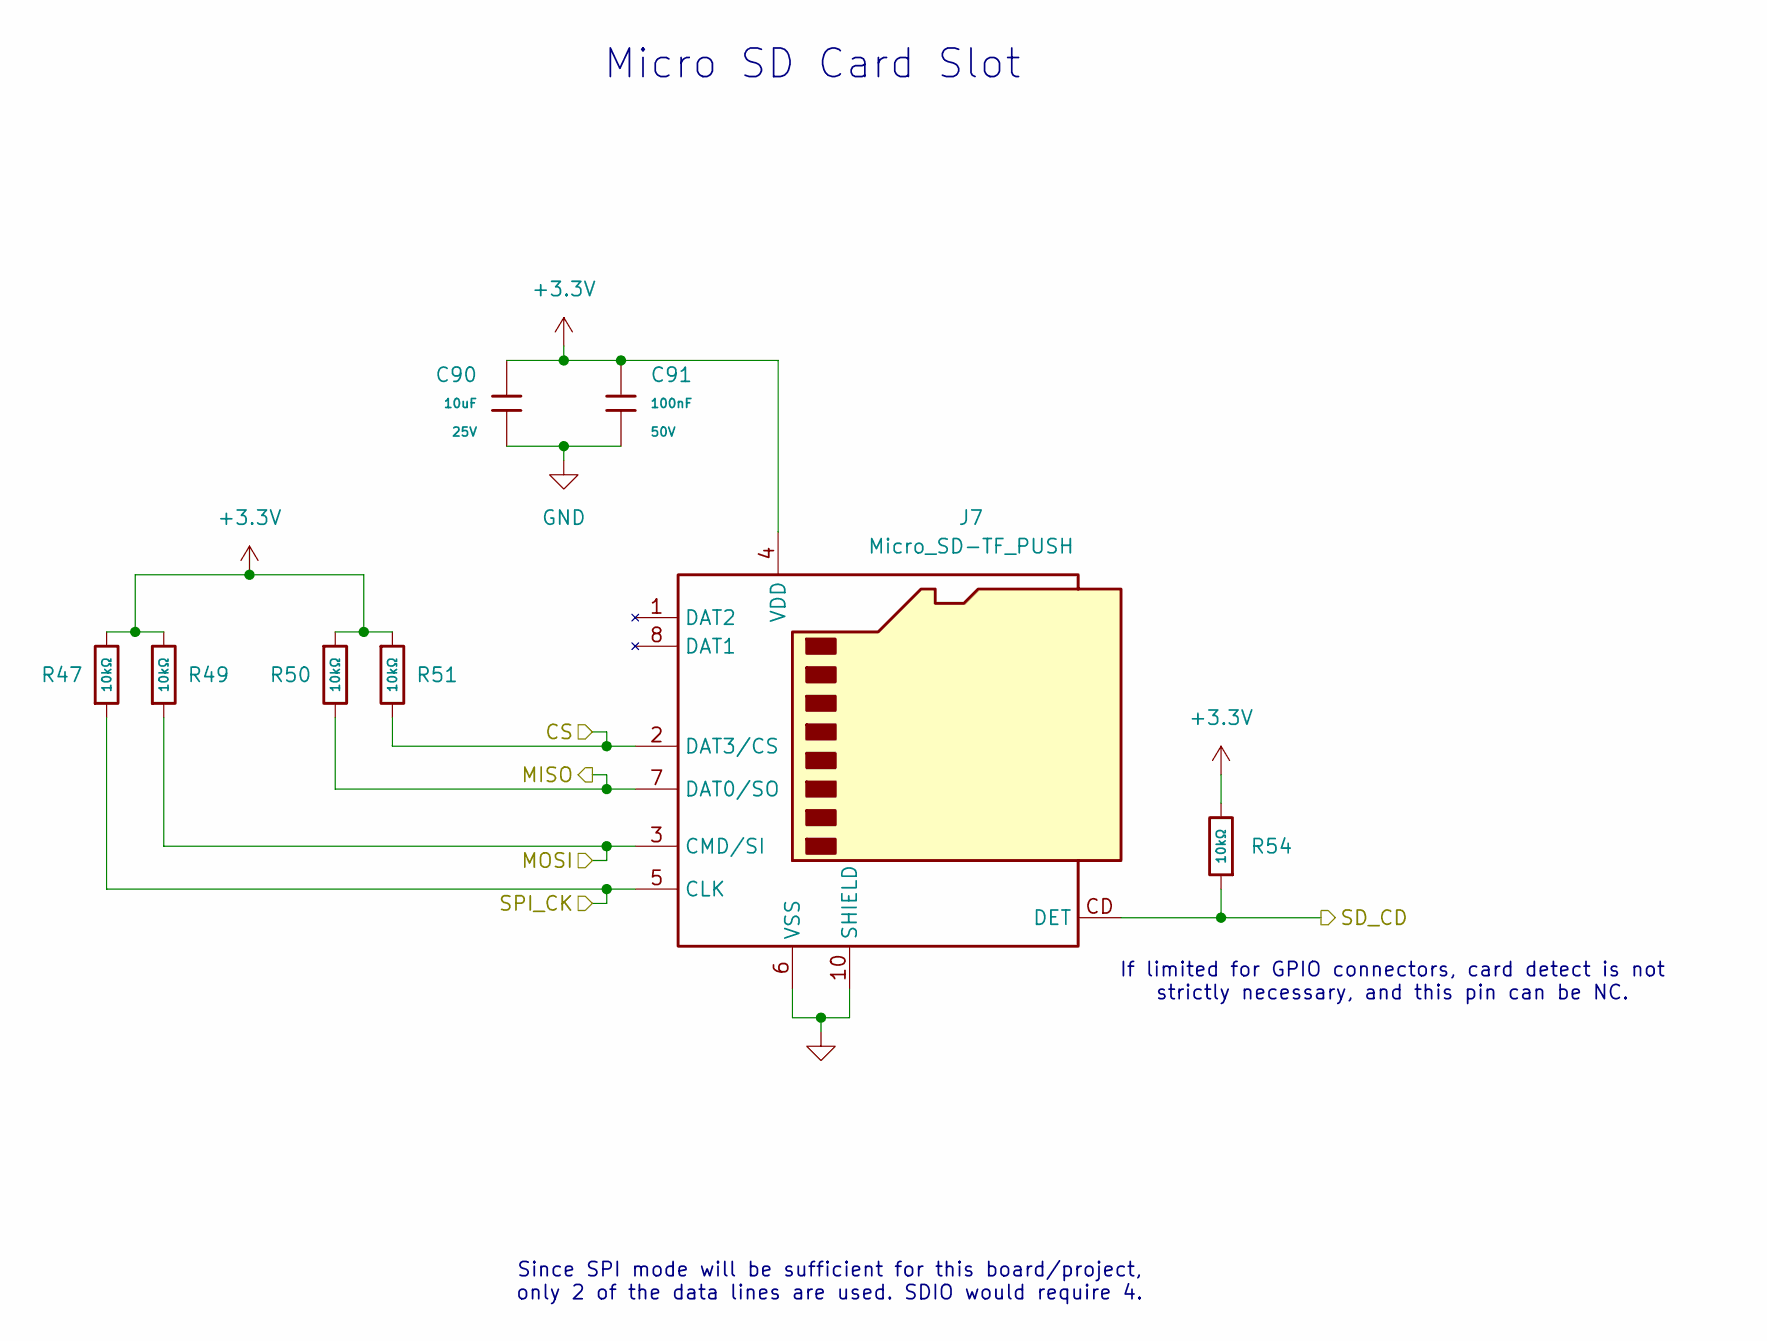
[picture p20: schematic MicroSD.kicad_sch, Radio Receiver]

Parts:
C90: 10uF; C_0805; Voltage Rated 25V; Tolerance ±10%; Part CL21A106KAYNNNE; LCSC C15850
C91: 100nF; C_0603; Voltage Rated 50V; Tolerance ±10%; Part CC0603KRX7R9BB104; LCSC C14663
J7: Micro_SD-TF_PUSH; TF-SMD_TF-PUSH; LCSC C393941
R47, R49, R50, R51, R54: 10kΩ; R_0603; Overload Voltage (Max) 75V; Tolerance ±1%; Part 0603WAF1002T5E; LCSC C25804

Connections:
+3.3V: C90.1, C91.1, J7.4 (VDD), R47.2, R49.2, R50.1, R51.1, R54.2; also elsewhere on the board
/CS: J7.2 (DAT3/CS), R51.2; also elsewhere on the board
/MISO: J7.7 (DAT0/SO), R50.2; also elsewhere on the board
/MOSI: J7.3 (CMD/SI), R49.1; also elsewhere on the board
/SD_CD: J7.CD (DET), R54.1; also elsewhere on the board
/SPI_CK: J7.5 (CLK), R47.1; also elsewhere on the board
GND: C90.2, C91.2, J7.6 (VSS), J7.10 (SHIELD), J7.11 (SHIELD), J7.12 (SHIELD), J7.13 (SHIELD); also elsewhere on the board

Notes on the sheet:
Since SPI mode will be sufficient for this board/project, only 2 of the data lines are used. SDIO would require 4.
Micro SD Card Slot
If limited for GPIO connectors, card detect is not strictly necessary, and this pin can be NC.

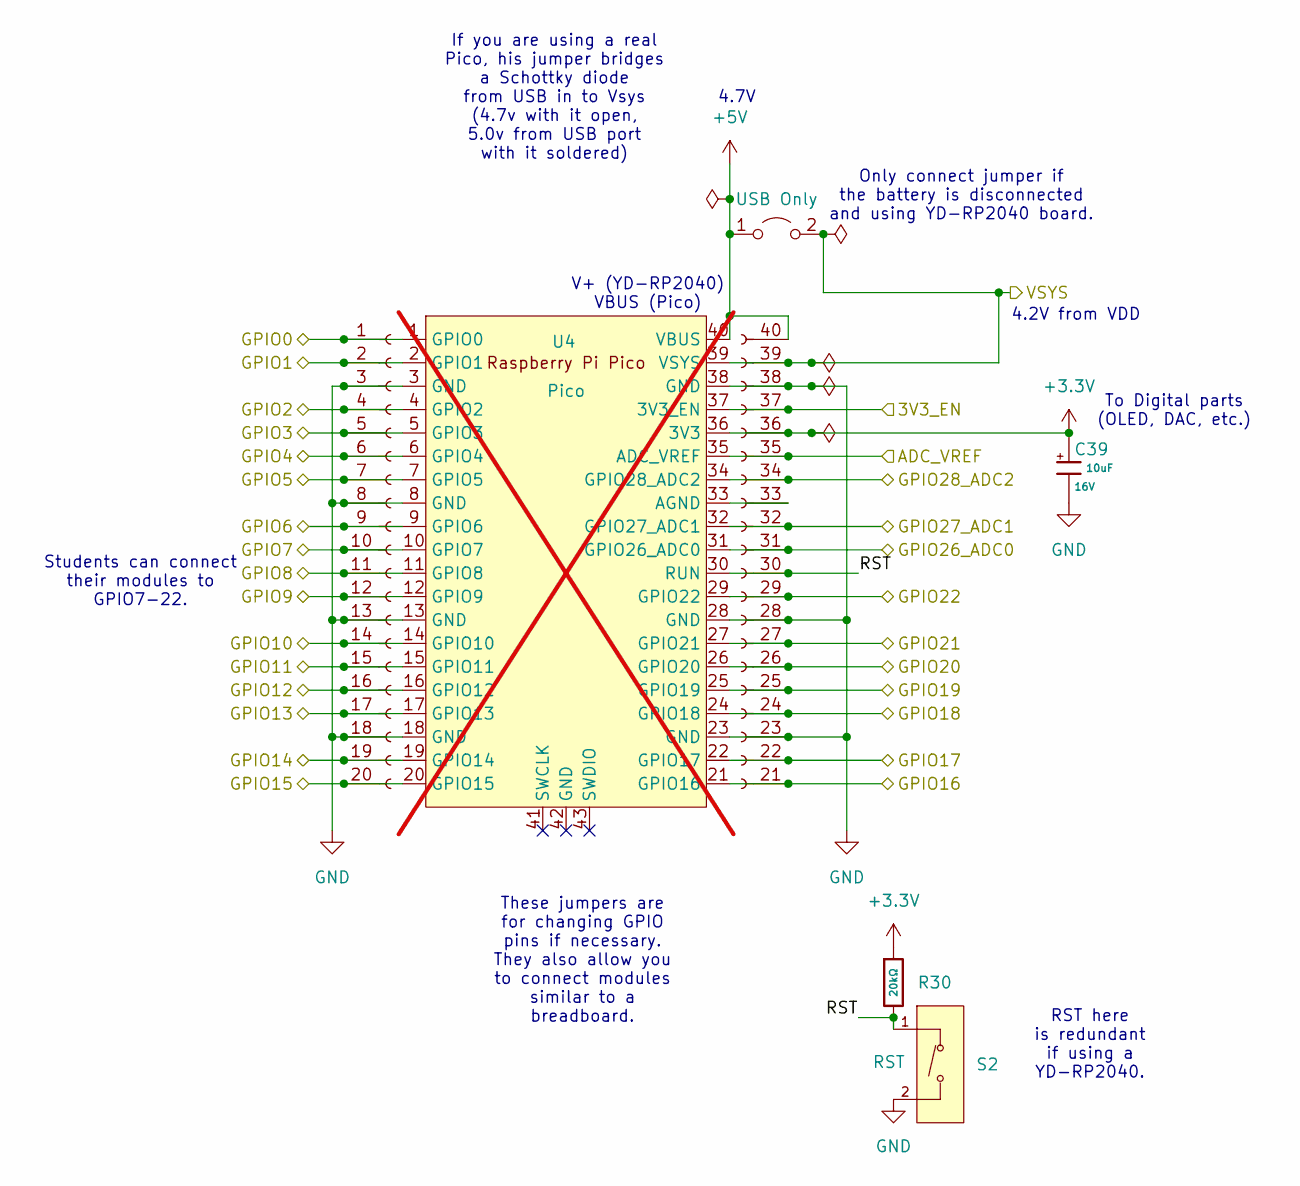
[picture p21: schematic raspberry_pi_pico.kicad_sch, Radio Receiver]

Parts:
C39: 10uF; C_CASE-A-3216-18(mm); Tolerance ±10%; Rated Voltage 16V; Part TAJA106K016RNJ; LCSC C7171
J27, J29: Conn_01x20_Socket; LCSC C2905423
JP69: USB Only; SolderJumper-2_P1.3mm_Open_RoundedPad1.0x1.5mm
R30: 20kΩ; R_0805; Overload Voltage (Max) 150V; Tolerance ±1%; Part 0805W8F2002T5E; LCSC C4328
S2: Tactile Button, 160gf; SW_TS-1088-AR02016; Voltage Rating (Dc) 12V; Part TS-1088-AR02016; LCSC C720477
U4: Pico; RPi_Pico_SMD_TH; not fitted

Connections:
+3.3V: C39.1, J29.36 (Pin_5), R30.1, U4.36 (3V3); also elsewhere on the board
+5V: J29.40 (Pin_1), JP69.1 (A), U4.40 (VBUS); also elsewhere on the board
/ANG_A: J29.27 (Pin_14), U4.27 (GPIO21); also elsewhere on the board
/ANG_B: J29.26 (Pin_15), U4.26 (GPIO20); also elsewhere on the board
/BCK: J27.20, U4.20 (GPIO15); also elsewhere on the board
/BCKO: J27.12, U4.12 (GPIO9); also elsewhere on the board
/CS: J27.2, U4.2 (GPIO1); also elsewhere on the board
/CTL1: J29.25 (Pin_16), U4.25 (GPIO19); also elsewhere on the board
/CTL2: J29.24 (Pin_17), U4.24 (GPIO18); also elsewhere on the board
/DATA: J27.11, U4.11 (GPIO8); also elsewhere on the board
/FMT: J27.10, U4.10 (GPIO7); also elsewhere on the board
/LRCK: J29.21 (Pin_20), U4.21 (GPIO16); also elsewhere on the board
/MCLK: J29.22 (Pin_19), U4.22 (GPIO17); also elsewhere on the board
/MD1: J27.15, U4.15 (GPIO11); also elsewhere on the board
/MISO: J27.1, U4.1 (GPIO0); also elsewhere on the board
/MOSI: J27.5, U4.5 (GPIO3); also elsewhere on the board
/MUTE: J27.9, U4.9 (GPIO6); also elsewhere on the board
/Raspberry_Pi_Pico/3V3_EN: J29.37 (Pin_4), U4.37 (3V3_EN)
/Raspberry_Pi_Pico/ADC_VREF: J29.35 (Pin_6), U4.35 (ADC_VREF)
/Raspberry_Pi_Pico/GPIO5: J27.7, U4.7 (GPIO5); also elsewhere on the board
/Raspberry_Pi_Pico/GPIO12: J27.16, U4.16 (GPIO12); also elsewhere on the board
/Raspberry_Pi_Pico/GPIO13: J27.17, U4.17 (GPIO13); also elsewhere on the board
/Raspberry_Pi_Pico/GPIO26_ADC0: J29.31 (Pin_10), U4.31 (GPIO26_ADC0)
/Raspberry_Pi_Pico/GPIO27_ADC1: J29.32 (Pin_9), U4.32 (GPIO27_ADC1)
/Raspberry_Pi_Pico/GPIO28_ADC2: J29.34 (Pin_7), U4.34 (GPIO28_ADC2)
/Raspberry_Pi_Pico/RST: J29.30 (Pin_11), R30.2, S2.1 (A), U4.30 (RUN)
/Raspberry_Pi_Pico/VSYS: J29.39 (Pin_2), JP69.2 (B), U4.39 (VSYS); also elsewhere on the board
/SDIN: J27.19, U4.19 (GPIO14); also elsewhere on the board
/SD_CD: J27.6, U4.6 (GPIO4); also elsewhere on the board
/SPI_CK: J27.4, U4.4 (GPIO2); also elsewhere on the board
/SW_C: J29.29 (Pin_12), U4.29 (GPIO22); also elsewhere on the board
/WS: J27.14, U4.14 (GPIO10); also elsewhere on the board
GND: C39.2, J27.3, J27.8, J27.13, J27.18, J29.23 (Pin_18), J29.28 (Pin_13), J29.38 (Pin_3), S2.2 (B), U4.3 (GND), U4.8 (GND), U4.13 (GND), U4.18 (GND), U4.23 (GND), U4.28 (GND), U4.38 (GND); also elsewhere on the board
unnamed: J29.33 (Pin_8), U4.33 (AGND)

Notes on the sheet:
Only connect jumper if the battery is disconnected and using YD-RP2040 board.
V+ (YD-RP2040) VBUS (Pico)
4.7V
4.2V from VDD
If you are using a real Pico, his jumper bridges a Schottky diode from USB in to Vsys (4.7v with it open, 5.0v from USB port with it soldered)
To Digital parts (OLED, DAC, etc.)
RST here is redundant if using a YD-RP2040.
Students can connect their modules to GPIO7-22.
These jumpers are for changing GPIO pins if necessary. They also allow you to connect modules similar to a breadboard.

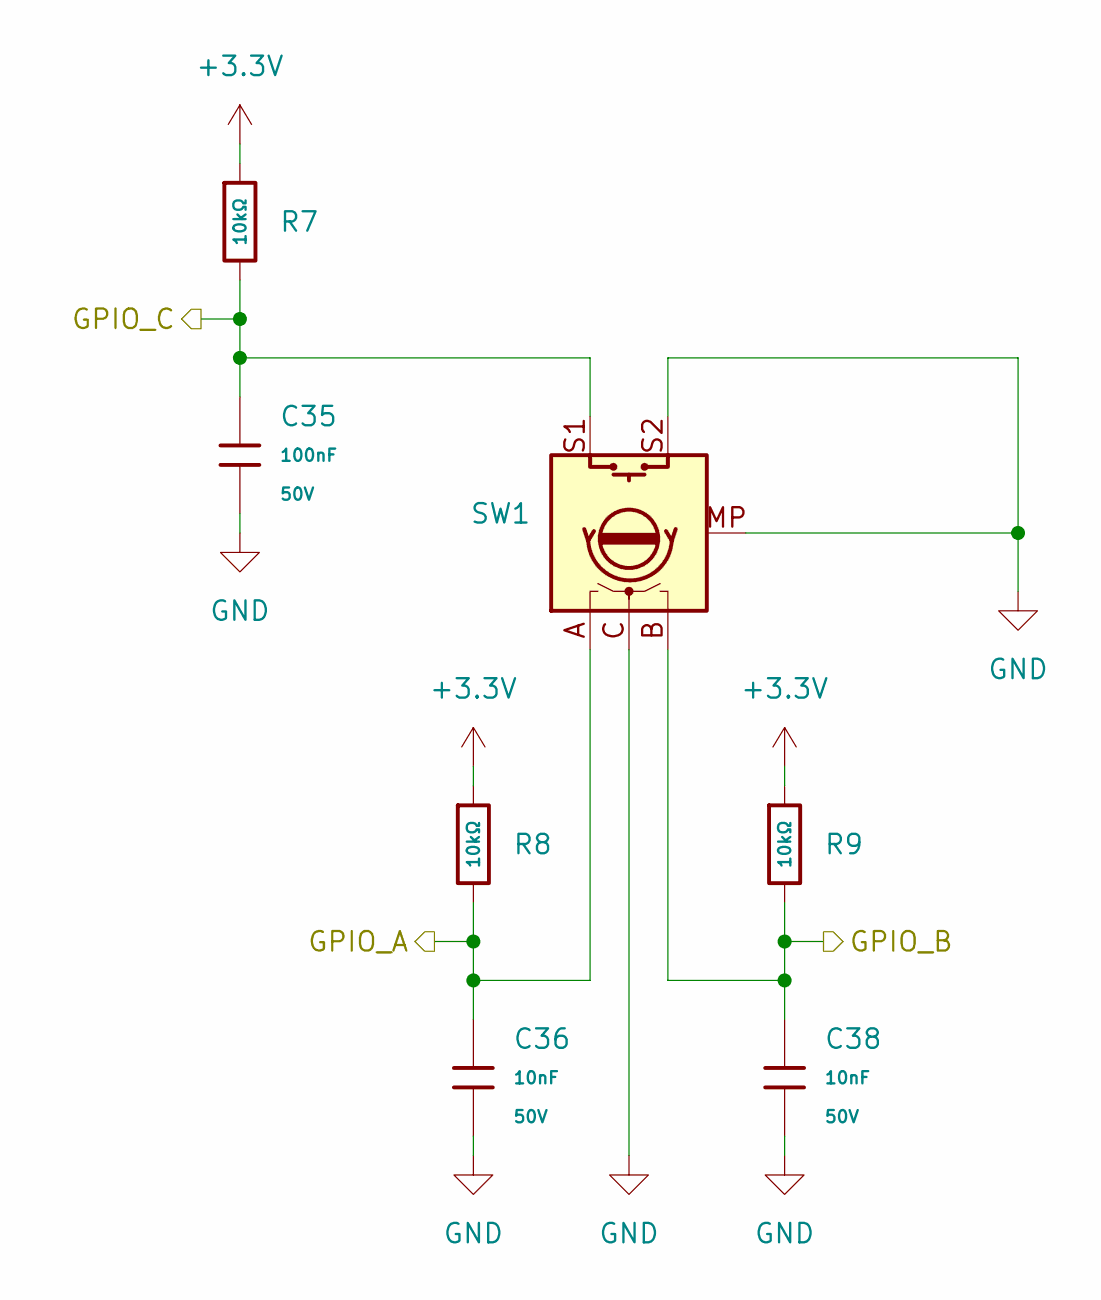
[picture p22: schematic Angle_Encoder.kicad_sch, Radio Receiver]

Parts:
C35: 100nF; C_0402; Voltage Rated 50V; Tolerance ±10%; Part CL05B104KB54PNC; LCSC C307331
C36, C38: 10nF; C_0402; Voltage Rated 50V; Tolerance ±10%; Part CL05B103KB5NNNC; LCSC C15195
R7, R8, R9: 10kΩ; R_0402; Overload Voltage (Max) 50V; Tolerance ±1%; Part 0402WGF1002TCE; LCSC C25744
SW1: RotaryEncoder_Switch_MP; RotaryEncoder_Alps_EC11E-Switch_Vertical_H20mm; LCSC C202365

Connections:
+3.3V: R7.1, R8.1, R9.1; also elsewhere on the board
/ANG_A: C36.1, R8.2, SW1.A; also elsewhere on the board
/ANG_B: C38.1, R9.2, SW1.B; also elsewhere on the board
/SW_C: C35.1, R7.2, SW1.S1; also elsewhere on the board
GND: C35.2, C36.2, C38.2, SW1.C, SW1.MP, SW1.S2; also elsewhere on the board

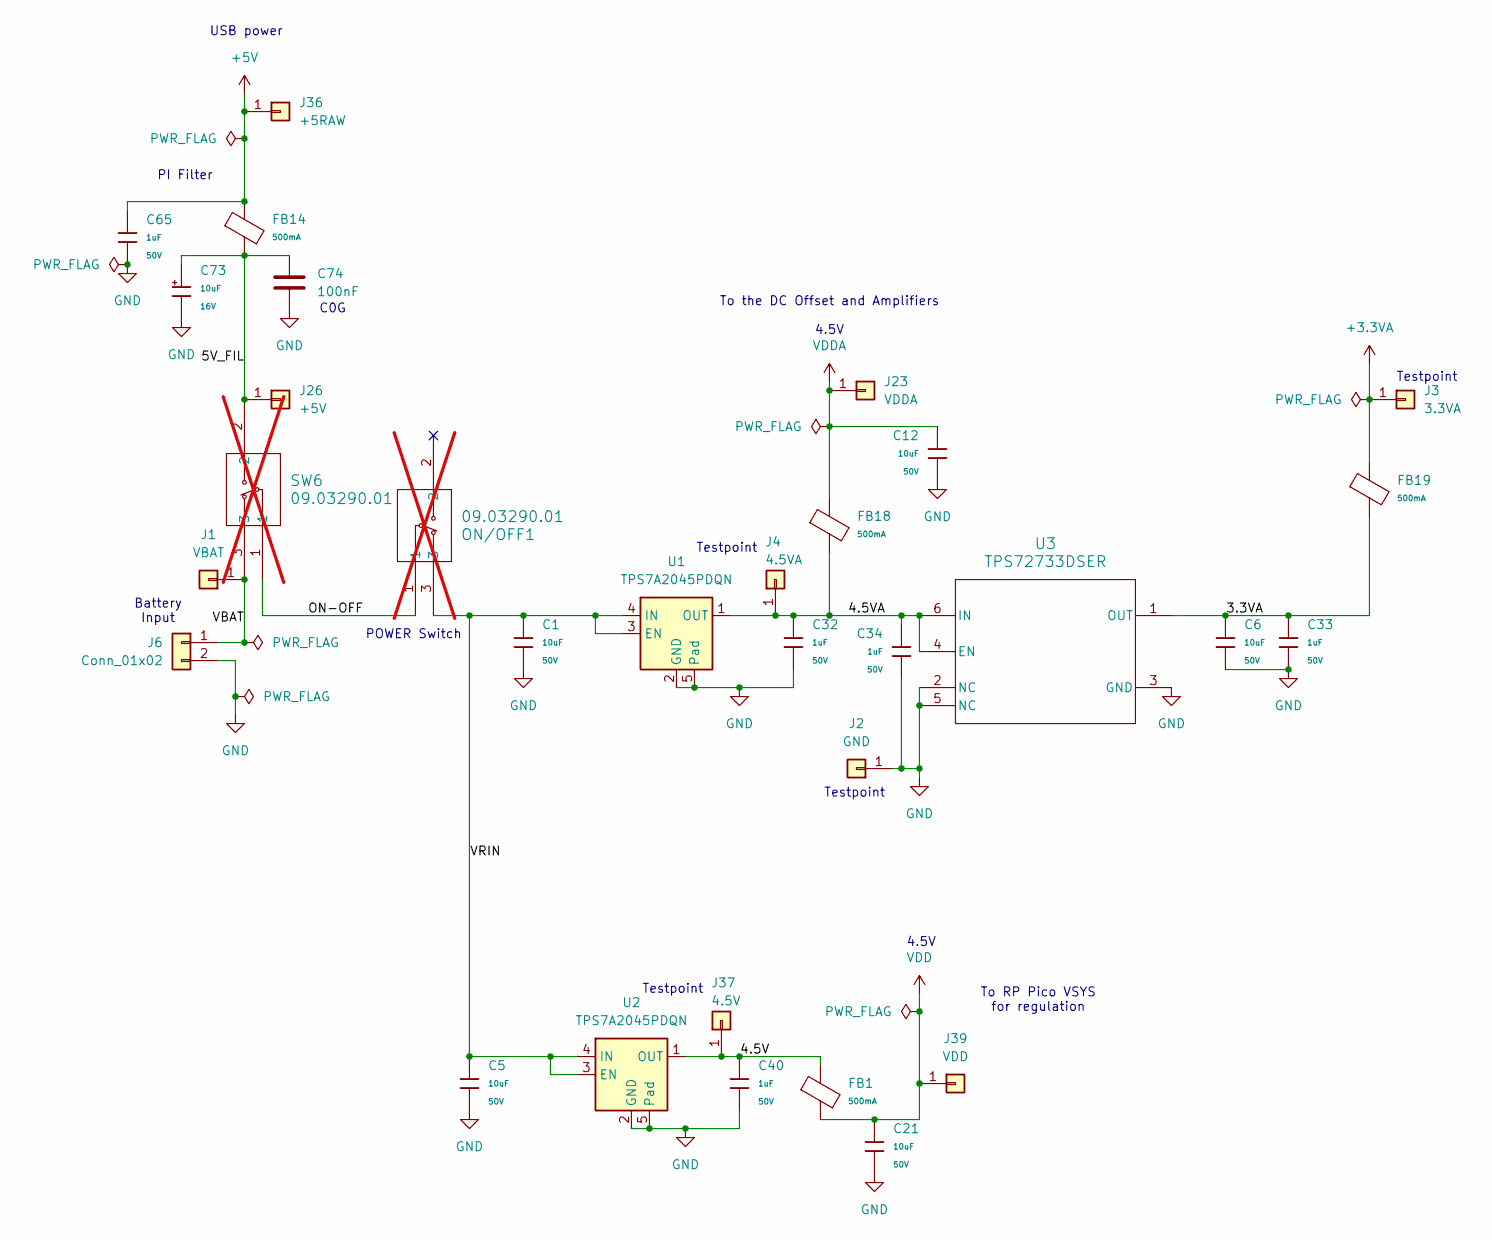
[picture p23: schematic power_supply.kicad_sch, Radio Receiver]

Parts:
C1, C5, C6, C12, C21: 10uF; C_0805; Voltage Rated 50V; Tolerance ±10%; Part GRM21BR61H106KE43L; LCSC C440198
C32, C33, C34, C40, C65: 1uF; C_0603; Voltage Rated 50V; Tolerance ±10%; Part CL10A105KB8NNNC; LCSC C15849
C73: 10uF; C_CASE-A-3216-18(mm); Tolerance ±10%; Rated Voltage 16V; Part TAJA106K016RNJ; LCSC C7171
C74: 100nF; C_1206; LCSC C52147198
FB1, FB14, FB18, FB19: FB_0805; Current Rating 500mA; Tolerance ±25%; Part GZ2012D601TF; LCSC C1017
J1: VBAT; PinHeader_1x01_P2.54mm_Vertical
J2: GND; PinHeader_1x01_P2.54mm_Vertical
J3: 3.3VA; PinHeader_1x01_P2.54mm_Vertical
J4: 4.5VA; PinHeader_1x01_P2.54mm_Vertical
J6: Conn_01x02; PinHeader_1x02_P2.54mm_Vertical
J23: VDDA; PinHeader_1x01_P2.54mm_Vertical
J26: +5V; PinHeader_1x01_P2.54mm_Vertical
J36: +5RAW; PinHeader_1x01_P2.54mm_Vertical
J37: 4.5V; PinHeader_1x01_P2.54mm_Vertical
J39: VDD; PinHeader_1x01_P2.54mm_Vertical
ON/OFF1: 09.03290.01; 09.03290_EAO; not fitted
SW6: 09.03290.01; 09.03290_EAO; not fitted
U1, U2: TPS7A2045PDQN; Texas_X2SON-4_1x1mm_P0.65mm; LCSC C3752275
U3: TPS72733DSER; TS727_3.3VDSE0006A; LCSC C544524

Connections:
+3.3VA: FB19.1, J3.1 (Pin_1_1); also elsewhere on the board
+5V: C65.1, FB14.1, J36.1 (Pin_1_1); also elsewhere on the board
/Power Supply/3.3VA: C6.1, C33.1, FB19.2, U3.1 (OUT)
/Power Supply/4.5V: C40.1, FB1.1, J37.1 (Pin_1_1), U2.1 (OUT)
/Power Supply/4.5VA: C32.1, C34.2, FB18.2, J4.1 (Pin_1_1), U1.1 (OUT), U3.4 (EN), U3.6 (IN)
/Power Supply/5V_FIL: C73.1, C74.1, FB14.2, J26.1 (Pin_1_1), SW6.2
/Power Supply/ON-OFF: ON/OFF1.1, SW6.1
/Power Supply/VBAT: J1.1 (Pin_1_1), J6.1, SW6.3
/Power Supply/VRIN: C1.1, C5.1, ON/OFF1.3, U1.3 (EN), U1.4 (IN), U2.3 (EN), U2.4 (IN)
GND: C1.2, C5.2, C6.2, C12.2, C21.2, C32.2, C33.2, C34.1, C40.2, C65.2, C73.2, C74.2, J2.1 (Pin_1_1), J6.2, U1.2 (GND), U1.5 (Pad), U2.2 (GND), U2.5 (Pad), U3.2 (NC), U3.3 (GND), U3.5 (NC); also elsewhere on the board
VDD: C21.1, FB1.2, J39.1 (Pin_1_1); also elsewhere on the board
VDDA: C12.1, FB18.1, J23.1 (Pin_1_1); also elsewhere on the board

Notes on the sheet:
4.5V
USB power
Testpoint
POWER Switch
Battery Input
C0G
To the DC Offset and Amplifiers
To RP Pico VSYS for regulation
PI Filter

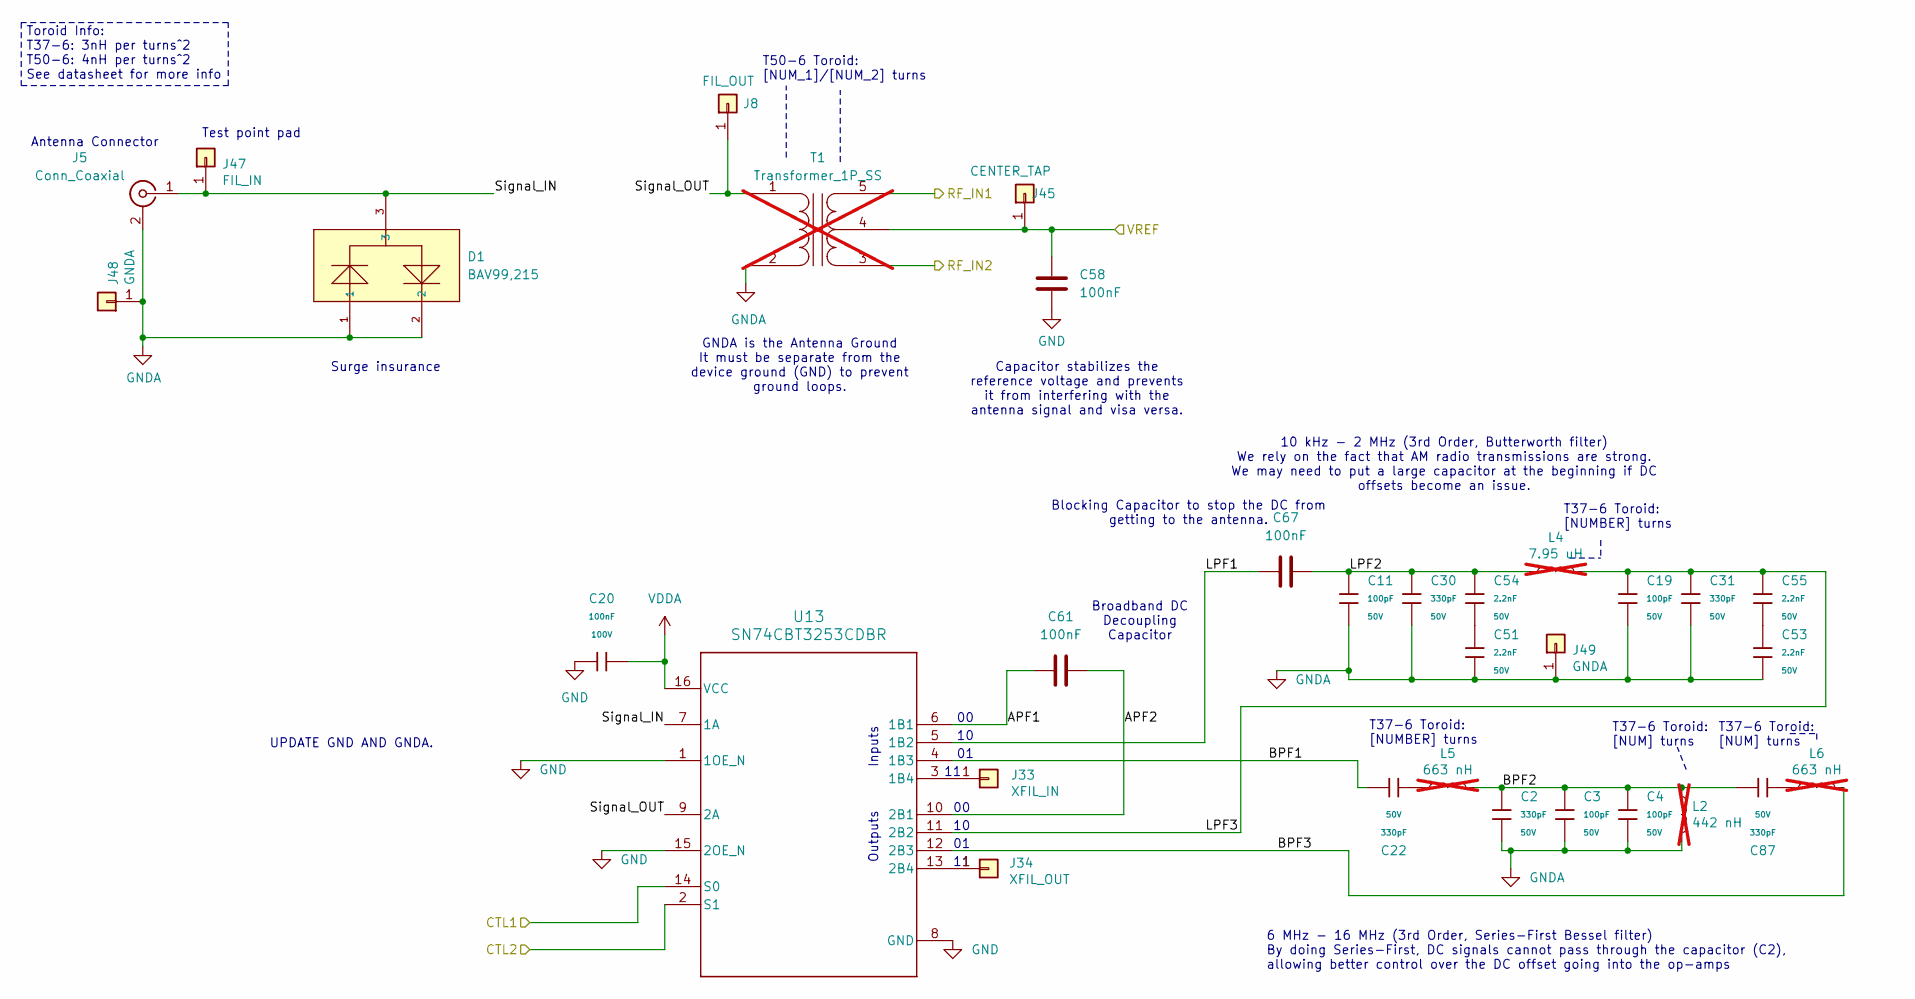
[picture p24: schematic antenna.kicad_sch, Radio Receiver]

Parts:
C2, C22, C30, C31, C87: 330pF; C_0603; Voltage Rated 50V; Tolerance ±5%; Part CL10C331JB8NNNC; LCSC C1664
C3, C4, C11, C19: 100pF; C_0402; Voltage Rated 50V; Tolerance ±5%; Part 0402CG101J500NT; LCSC C1546
C20: 100nF; C_0805; Voltage Rated 100V; Tolerance ±10%; Part CL21B104KCFNNNE; LCSC C28233
C51, C53, C54, C55: 2.2nF; C_0805; Voltage Rated 50V; Tolerance ±5%; Part CL21C222JBFNNNE; LCSC C28260
C58, C61, C67: 100nF; C_1206; LCSC C52147198
D1: BAV99,215; SOT-23-3_L3.0-W1.7-P0.95-LS2.9-BR; Reverse Voltage (Vr) 100V; Forward Voltage (Vf@If) 1.25V@150mA; Part BAV99,215; LCSC C2500
J5: Conn_Coaxial; Conn_Coaxial_Frohne
J8: FIL_OUT; PinHeader_1x01_P2.54mm_Vertical
J33: XFIL_IN; PinHeader_1x01_P2.54mm_Vertical
J34: XFIL_OUT; PinHeader_1x01_P2.54mm_Vertical
J45: CENTER_TAP; PinHeader_1x01_P2.54mm_Vertical
J47: FIL_IN; PinHeader_1x01_P2.54mm_Vertical
J48, J49: GNDA; PinHeader_1x01_P2.54mm_Vertical
L2: 442 nH; L_Toroid_Vertical_L10.0mm_W5.0mm_P5.08mm; not fitted
L4: 7.95 uH; L_Toroid_Vertical_L13.0mm_W6.5mm_P5.60mm; not fitted
L5, L6: 663 nH; L_Toroid_Vertical_L13.0mm_W6.5mm_P5.60mm; not fitted
T1: Transformer_1P_SS; Transformer_Toroid_Vertical_2Pri_3Sec_T37; not fitted
U13: SN74CBT3253CDBR; DB0016A_N; LCSC C2674583

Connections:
/Antenna/APF1: C61.1, U13.6 (1B1)
/Antenna/APF2: C61.2, U13.10 (2B1)
/Antenna/BPF1: C22.1, U13.4 (1B3)
/Antenna/BPF2: C2.1, C3.1, C4.1, C87.1, L2.1, L5.2
/Antenna/BPF3: L6.2, U13.12 (2B3)
/Antenna/LPF1: C67.1, U13.5 (1B2)
/Antenna/LPF2: C11.1, C30.1, C54.1, C67.2, L4.1
/Antenna/LPF3: C19.1, C31.1, C55.1, L4.2, U13.11 (2B2)
/Antenna/Signal_IN: D1.3, J5.1 (In), J47.1 (Pin_1_1), U13.7 (1A)
/Antenna/Signal_OUT: J8.1 (Pin_1_1), T1.1 (AA), U13.9 (2A)
/CTL1: U13.14 (S0); also elsewhere on the board
/CTL2: U13.2 (S1); also elsewhere on the board
/RF_IN1: T1.5 (SB); also elsewhere on the board
/RF_IN2: T1.3 (SA); also elsewhere on the board
/VREF: C58.1, J45.1 (Pin_1_1), T1.4 (SC); also elsewhere on the board
GND: C20.1, C58.2, U13.1 (1OE_N), U13.8 (GND), U13.15 (2OE_N); also elsewhere on the board
GNDA: C2.2, C3.2, C4.2, C11.2, C19.2, C30.2, C31.2, C51.2, C53.2, D1.1, D1.2, J5.2 (Ext), J48.1 (Pin_1_1), J49.1 (Pin_1_1), L2.2, T1.2 (AB)
unnamed: C22.2, L5.1
unnamed: C51.1, C54.2
unnamed: C53.1, C55.2
unnamed: C87.2, L6.1
unnamed: J33.1 (Pin_1_1), U13.3 (1B4)
unnamed: J34.1 (Pin_1_1), U13.13 (2B4)
VDDA: C20.2, U13.16 (VCC); also elsewhere on the board

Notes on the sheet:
Capacitor stabilizes the reference voltage and prevents it from interfering with the antenna signal and visa versa.
Broadband DC Decoupling Capacitor
T50-6 Toroid: [NUM_1]/[NUM_2] turns
Test point pad
T37-6 Toroid: [NUMBER] turns
Surge insurance
Blocking Capacitor to stop the DC from getting to the antenna.
T37-6 Toroid: [NUM] turns
10 kHz - 2 MHz (3rd Order, Butterworth filter) We rely on the fact that AM radio transmissions are strong. We may need to put a large capacitor at the beginning if DC offsets become an issue.
Toroid Info: T37-6: 3nH per turns^2 T50-6: 4nH per turns^2 See datasheet for more info
Outputs
T37-6 Toroid: [NUM] turns
UPDATE GND AND GNDA.
GNDA is the Antenna Ground It must be separate from the device ground (GND) to prevent ground loops.
Antenna Connector
6 MHz - 16 MHz (3rd Order, Series-First Bessel filter) By doing Series-First, DC signals cannot pass through the capacitor (C2), allowing better control over the DC offset going into the op-amps
Inputs

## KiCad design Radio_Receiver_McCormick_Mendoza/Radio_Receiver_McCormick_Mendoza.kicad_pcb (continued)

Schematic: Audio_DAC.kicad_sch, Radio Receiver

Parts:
C7, C17: 2.2uF; C_0805; Voltage Rated 50V; Tolerance ±10%; Part CL21A225KBQNNNE; LCSC C377773
C10, C41, C45, C46: 10uF; C_CASE-A-3216-18(mm); Tolerance ±10%; Rated Voltage 16V; Part TAJA106K016RNJ; LCSC C7171
C18, C37: 100nF; C_0402; Voltage Rated 50V; Tolerance ±10%; Part CL05B104KB54PNC; LCSC C307331
C42, C43: 2.2nF; C_0805; Voltage Rated 50V; Tolerance ±5%; Part CL21C222JBFNNNE; LCSC C28260
C49, C60, C88: 10uF; C_0805; Voltage Rated 50V; Tolerance ±10%; Part GRM21BR61H106KE43L; LCSC C440198
C50, C57: 100nF; C_0805; Voltage Rated 100V; Tolerance ±10%; Part CL21B104KCFNNNE; LCSC C28233
C59, C68, C85, C86, C89: 100uF; C_CASE-B-3528-21(mm); Tolerance ±10%; Rated Voltage 6.3V; Part TAJB107K006RNJ; LCSC C16133
C64: 1uF; C_0603; Voltage Rated 50V; Tolerance ±10%; Part CL10A105KB8NNNC; LCSC C15849
C66, C84, C96: 100nF; C_1206; LCSC C52147198
FB11, FB12: FB_0805; Current Rating 500mA; Tolerance ±25%; Part GZ2012D601TF; LCSC C1017
J35, J46: 3.5mm_Jack; Jack_3.5mm_CUI_SJ-3523-SMT_Horizontal; LCSC C18594
J38: DAC_FLT; PinHeader_1x01_P2.54mm_Vertical
J40: DAC_FMT; PinHeader_1x01_P2.54mm_Vertical
JP6, JP10: Jumper_2_Bridged; SolderJumper-2_P1.3mm_Bridged_RoundedPad1.0x1.5mm
R6: 47kΩ; R_0603; Overload Voltage (Max) 75V; Tolerance ±1%; Part 0603WAF4702T5E; LCSC C25819
R10, R29: 470Ω; R_0805; Overload Voltage (Max) 150V; Tolerance ±1%; Part 0805W8F4700T5E; LCSC C17710
R28, R43: 10Ω; R_0603; Overload Voltage (Max) 75V; Tolerance ±1%; Part 0603WAF100JT5E; LCSC C22859
R32, R42: 2.2Ω; R_0805; Overload Voltage (Max) 150V; Tolerance ±1%; Part 0805W8F220KT5E; LCSC C17521
R33, R44: 10kΩ; R_0805; Overload Voltage (Max) 150V; Tolerance ±1%; Part 0805W8F1002T5E; LCSC C17414
R45: 6.8kΩ; R_0603; Overload Voltage (Max) 75V; Tolerance ±1%; Part 0603WAF6801T5E; LCSC C23212
R48: 33Ω; R_0805; Overload Voltage (Max) 150V; Tolerance ±1%; Part 0805W8F330JT5E; LCSC C17634
U14: PCM5102A; TSSOP-20_4.4x6.5mm_P0.65mm; LCSC C107671
e3, e4: Groundloop_Insurance; SolderJumper-2_P1.3mm_Bridged_RoundedPad1.0x1.5mm

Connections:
+3.3V: C37.1, C46.1, U14.20 (DVDD); also elsewhere on the board
+3.3VA: R32.1, R42.1; also elsewhere on the board
/Audio DAC/3.3VA: C64.1, FB11.1, R32.2
/Audio DAC/AVDD: C10.1, C66.1, FB11.2, U14.8 (AVDD)
/Audio DAC/CPVDD: C41.1, C84.1, FB12.2, U14.1 (CPVDD)
/Audio DAC/JackS1: C50.2, J35.S, R28.1, e3.2 (B)
/Audio DAC/MONO: C59.2, C68.2, C85.2, C86.2, C89.2, C96.2, R48.1
/Audio DAC/MONO_OUT: J46.R, J46.T, R48.2
/Audio DAC/OUTL: R10.1, U14.6 (OUTL)
/Audio DAC/OUTLR: C49.1, R33.2, R44.1, R45.2
/Audio DAC/OUTL_FIL: C43.1, C88.2, R10.2, R33.1
/Audio DAC/OUTR: R29.2, U14.7 (OUTR)
/Audio DAC/OUTR_FIL: C42.1, C60.1, R29.1, R44.2
/Audio DAC/SCK: U14.12 (SCK); also elsewhere on the board
/Audio DAC/StereoR: C60.2, J35.R
/Audio DAC/StereoT: C88.1, J35.T
/BCK: U14.13 (BCK); also elsewhere on the board
/LRCK: U14.15 (LRCK); also elsewhere on the board
/MUTE: U14.17 (XSMT); also elsewhere on the board
/SDIN: U14.14 (DIN); also elsewhere on the board
AMP+: C49.2, R6.2; also elsewhere on the board
AMP-: C59.1, C68.1, C85.1, C86.1, C89.1, C96.1; also elsewhere on the board
GND: C7.2, C10.2, C18.2, C37.2, C41.2, C42.2, C43.2, C45.2, C46.2, C50.1, C64.2, C66.2, C84.2, JP6.1 (A), JP10.2 (B), R28.2, R43.2, R45.1, U14.3 (CPGND), U14.9 (AGND), U14.10 (DEMP), U14.19 (DGND), e3.1 (A); also elsewhere on the board
unnamed: FB12.1, R42.2
unnamed: J38.1 (Pin_1_1), JP6.2 (B), U14.11 (FLT)
unnamed: J40.1 (Pin_1_1), JP10.1 (A), U14.16 (FMT)
unnamed: C17.1, U14.4 (CAPM)
unnamed: C17.2, U14.2 (CAPP)
unnamed: C18.1, C45.1, U14.18 (LDOO)
unnamed: C7.1, U14.5 (VNEG)
unnamed: C57.1, e4.1 (A)
unnamed: C57.2, J46.S, R43.1, e4.2 (B)
V_DIV: R6.1; also elsewhere on the board

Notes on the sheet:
PI Filter
Place this charge pump capacitor as close as possible to the DAC to minimize noise radiated from the traces.
Non-inverting amplifier here to drive head phones.
C0G
High impedance loads ONLY (e.g. ACS90 speakers)
500.1uF Bank
OPA1612 HP Low-Noise Amp
Low impedance loads ONLY (e.g. Anker Soundcore Q20)

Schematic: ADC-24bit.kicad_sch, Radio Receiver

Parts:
C16: 10uF; C_0805; Voltage Rated 50V; Tolerance ±10%; Part GRM21BR61H106KE43L; LCSC C440198
C23, C24: 2.2nF; C_0805; Voltage Rated 50V; Tolerance ±5%; Part CL21C222JBFNNNE; LCSC C28260
C25, C28, C44, C98: 10uF; C_CASE-A-3216-18(mm); Tolerance ±10%; Rated Voltage 16V; Part TAJA106K016RNJ; LCSC C7171
C26, C27, C29, C52: 100nF; C_0805; Voltage Rated 100V; Tolerance ±10%; Part CL21B104KCFNNNE; LCSC C28233
C47, C48: 1uF; C_0805; Voltage Rated 50V; Tolerance ±10%; Part CL21B105KBFNNNE; LCSC C28323
C83: 100nF; C_1206; LCSC C52147198
C93, C97: 1uF; C_0603; Voltage Rated 50V; Tolerance ±10%; Part CL10A105KB8NNNC; LCSC C15849
C94, C95: 100nF; C_0402; Voltage Rated 50V; Tolerance ±10%; Part CL05B104KB54PNC; LCSC C307331
FB20, FB21: FB_0805; Current Rating 500mA; Tolerance ±25%; Part GZ2012D601TF; LCSC C1017
J21: SDR Out; Jack_3.5mm_CUI_SJ-3523-SMT_Horizontal; LCSC C18594
J41: V_DIV; PinHeader_1x01_P2.54mm_Vertical
J42: VDDA/2; PinHeader_1x01_P2.54mm_Vertical
JP5: Jumper_2_Bridged; SolderJumper-2_P1.3mm_Bridged_RoundedPad1.0x1.5mm
JP11: Jumper_2_Open; SolderJumper-2_P1.3mm_Open_RoundedPad1.0x1.5mm
R3: 1kΩ; R_0402; Overload Voltage (Max) 50V; Tolerance ±1%; Part 0402WGF1001TCE; LCSC C11702
R5: 22Ω; R_0603; Overload Voltage (Max) 75V; Tolerance ±1%; Part 0603WAF220JT5E; LCSC C23345
R17, R18: 430Ω; R_0603; Overload Voltage (Max) 75V; Tolerance ±1%; Part 0603WAF4300T5E; LCSC C23170
R19, R20, R21: 33Ω; R_0805; Overload Voltage (Max) 150V; Tolerance ±1%; Part 0805W8F330JT5E; LCSC C17634
R31: 10Ω; R_0603; Overload Voltage (Max) 75V; Tolerance ±1%; Part 0603WAF100JT5E; LCSC C22859
R46: 2.2Ω; R_0805; Overload Voltage (Max) 150V; Tolerance ±1%; Part 0805W8F220KT5E; LCSC C17521
R52, R53: 22kΩ; R_0805; Overload Voltage (Max) 150V; Tolerance ±1%; Part 0805W8F2202T5E; LCSC C17560
U10: OPA1612AID; D8-M; LCSC C2871441
U12: PCM1808PWR; TSSOP-14_4.4x5mm_P0.65mm; PARTREV B; LCSC C55513
e5: Groundloop_Insurance; SolderJumper-2_P1.3mm_Bridged_RoundedPad1.0x1.5mm

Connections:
+3.3V: C25.1, C26.2, U12.4 (VDD), U12.10 (MD0); also elsewhere on the board
/ADC-24bit/Buf_IN: C16.1, JP5.1 (A), JP11.2 (B), U10.3 (+)
/ADC-24bit/I_OUTA: C47.1, J21.R, R17.1
/ADC-24bit/JackS: C52.2, J21.S, R31.1, e5.2 (B)
/ADC-24bit/OPA_OUT: R5.1, U10.1, U10.2 (-)
/ADC-24bit/Q_OUTA: C48.1, J21.T, R18.1
/ADC-24bit/SCKI: U12.6 (SCKI); also elsewhere on the board
/ADC-24bit/V+: C83.1, C98.1, FB20.2, U10.8 (V+)
/ADC-24bit/VDDA2: C97.1, FB20.1, R46.2
/ADC-24bit/VINL: C23.1, R17.2, U12.13 (VINL)
/ADC-24bit/VINR: C24.1, R18.2, U12.14 (VINR)
/ADC-24bit/VREF0: C27.2, C44.1, R3.1, U12.1 (VREF)
/BCKO: R20.2; also elsewhere on the board
/DATA: R19.2; also elsewhere on the board
/FMT: U12.12 (FMT); also elsewhere on the board
/I: C47.2; also elsewhere on the board
/MD1: U12.11 (MD1); also elsewhere on the board
/Q: C48.2; also elsewhere on the board
/VREF: J42.1 (Pin_1_1), R5.2; also elsewhere on the board
/WS: R21.2; also elsewhere on the board
AMP+: U10.5 (+); also elsewhere on the board
AMP-: U10.6 (-), U10.7; also elsewhere on the board
GND: C16.2, C23.2, C24.2, C25.2, C26.1, C27.1, C28.2, C29.1, C44.2, C52.1, C83.2, C93.2, C95.1, C97.2, C98.2, R31.2, R53.2, U10.4 (V-), U12.2 (AGND), U12.5 (DGND), e5.1 (A); also elsewhere on the board
unnamed: JP5.2 (B), R3.2
unnamed: R20.1, U12.8 (BCK)
unnamed: R19.1, U12.9 (DOUT)
unnamed: R21.1, U12.7 (LRCK)
VDDA: C28.1, C29.2, C93.1, C94.2, FB21.1, FB21.2, R46.1, R52.1, U12.3 (VCC); also elsewhere on the board
V_DIV: C94.1, C95.2, J41.1 (Pin_1_1), JP11.1 (A), R52.2, R53.1; also elsewhere on the board

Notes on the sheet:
OPA1612 High Performance Low-Noise Amp
GND and GNDA all the same second layer from the top. Follow the new way of making one big ground plane for the second layer and as much ground plane on top and bottom as possible, with the power plane on the third layer.
10 - 45 Ohm resistor "hides" the downstream capacitance from the Op-Amp, ensuring it stays stable.
24.576 MHz osc. (allows 48 kHz or 96 kHz)
BCK (BCKO)
Having the I and Q inputs here eliminates the mismatch between C1 and C4.
SD (DATA)
Second Op Amp and divided voltage go to DAC stage
24 Bit ADC
C0G
Place Audio Jack for Quisk Here
I2S
PI Filter
LRCK (WS)

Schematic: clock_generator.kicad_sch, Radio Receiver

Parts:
C8: 100nF; C_0402; Voltage Rated 50V; Tolerance ±10%; Part CL05B104KB54PNC; LCSC C307331
C56: 10nF; C_0805; Voltage Rated 50V; Tolerance ±10%; Part CL21B103KBANNNC; LCSC C1710
C70, C75: 1uF; C_0603; Voltage Rated 50V; Tolerance ±10%; Part CL10A105KB8NNNC; LCSC C15849
C71, C76, C80: 10uF; C_CASE-A-3216-18(mm); Tolerance ±10%; Rated Voltage 16V; Part TAJA106K016RNJ; LCSC C7171
C72, C77, C78: 100nF; C_1206; LCSC C52147198
FB13, FB15, FB16, FB17: FB_0805; Current Rating 500mA; Tolerance ±25%; Part GZ2012D601TF; LCSC C1017
J9: CLK_1; PinHeader_1x01_P2.54mm_Vertical
J10: CLK_2; PinHeader_1x01_P2.54mm_Vertical
J11: I_LO; PinHeader_1x01_P2.54mm_Vertical
J12: Q_LO; PinHeader_1x01_P2.54mm_Vertical
J24: CLK_0; PinHeader_1x01_P2.54mm_Vertical
JP12: Jumper_2_Open; SolderJumper-2_P1.3mm_Open_RoundedPad1.0x1.5mm
R1, R2: 1kΩ; R_0402; Overload Voltage (Max) 50V; Tolerance ±1%; Part 0402WGF1001TCE; LCSC C11702
R4, R41: 2.2Ω; R_0805; Overload Voltage (Max) 150V; Tolerance ±1%; Part 0805W8F220KT5E; LCSC C17521
R34, R35, R36: 33Ω; R_0805; Overload Voltage (Max) 150V; Tolerance ±1%; Part 0805W8F330JT5E; LCSC C17634
R39, R40: 22Ω; R_0603; Overload Voltage (Max) 75V; Tolerance ±1%; Part 0603WAF220JT5E; LCSC C23345
U5: Si5351A-B-GT; MSOP-10_3x3mm_P0.5mm; LCSC C504891
U6: SN74AC74DR; D14; LCSC C352945
Y1: ASTX-H11-24.576MHZ-T; XTAL_ASTX-H11-24.576MHZ-T; PARTREV 05.13.15; LCSC C1987701

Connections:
+3.3V: R1.1, R2.1; also elsewhere on the board
+3.3VA: C75.1, FB15.1, FB17.1, R4.1, R41.1; also elsewhere on the board
/ADC-24bit/SCKI: R34.1; also elsewhere on the board
/Clock Generator/3.3VA: C70.1, FB13.1, R41.2
/Clock Generator/CGVDD: C76.1, C77.1, FB15.2, U5.1 (VDD)
/Clock Generator/CGVDDO: C78.1, C80.1, FB16.2, U5.7 (VDDO)
/Clock Generator/CLK0: J24.1 (Pin_1_1), U5.10 (CLK0), U6.3 (C), U6.11 (C)
/Clock Generator/I_LO: J11.1 (Pin_1_1), R40.1, R40.2, U6.6 (~Q); also elsewhere on the board
/Clock Generator/JC5-12: U6.5 (Q), U6.12 (D)
/Clock Generator/JCVCC: C8.1, C71.1, C72.1, FB13.2, U6.1 (~R), U6.4 (~S), U6.10 (~S), U6.13 (~R), U6.14 (VCC)
/Clock Generator/Q_LO: J12.1 (Pin_1_1), R39.1, R39.2, U6.2 (D), U6.8 (~Q); also elsewhere on the board
/Clock Generator/XA: R35.2, U5.2 (XA)
/Clock Generator/Y1VDD: C56.1, FB17.2, Y1.1 (TRI_STATE), Y1.4 (VDD)
/Clock Generator/Y1_Pin3: JP12.2 (B), R34.2, R35.1, Y1.3 (OUTPUT)
/EX_CLK: R36.1; also elsewhere on the board
/OSC_SCL: R1.2, U5.4 (SCL); also elsewhere on the board
/OSC_SDA: R2.2, U5.5 (SDA); also elsewhere on the board
GND: C8.2, C56.2, C70.2, C71.2, C72.2, C75.2, C76.2, C77.2, C78.2, C80.2, U5.8 (GND), U6.7 (GND), Y1.2 (GND); also elsewhere on the board
unnamed: FB16.1, R4.2
unnamed: J9.1 (Pin_1_1), U5.9 (CLK1)
unnamed: J10.1 (Pin_1_1), U5.6 (CLK2)
unnamed: JP12.1 (A), R36.2

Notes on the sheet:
PI Filter
I2C
24.576 MHz
Johnson Counter CLK/4 Circuit using 74AC74
PI Filters
C0G

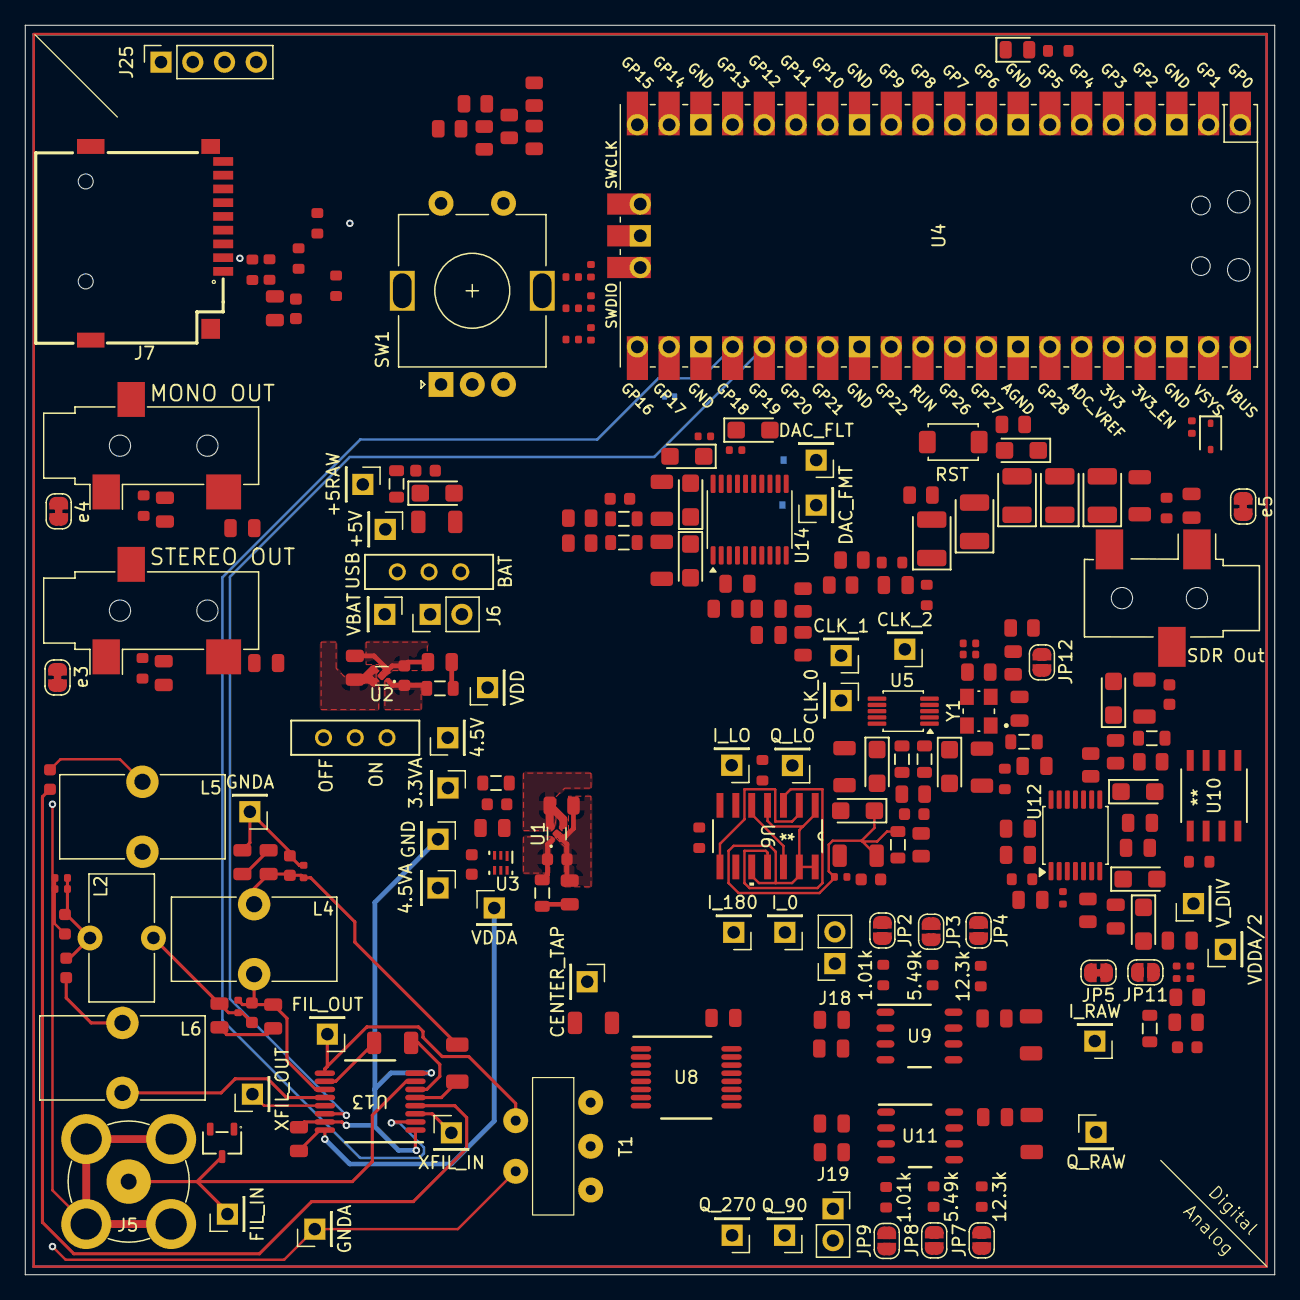
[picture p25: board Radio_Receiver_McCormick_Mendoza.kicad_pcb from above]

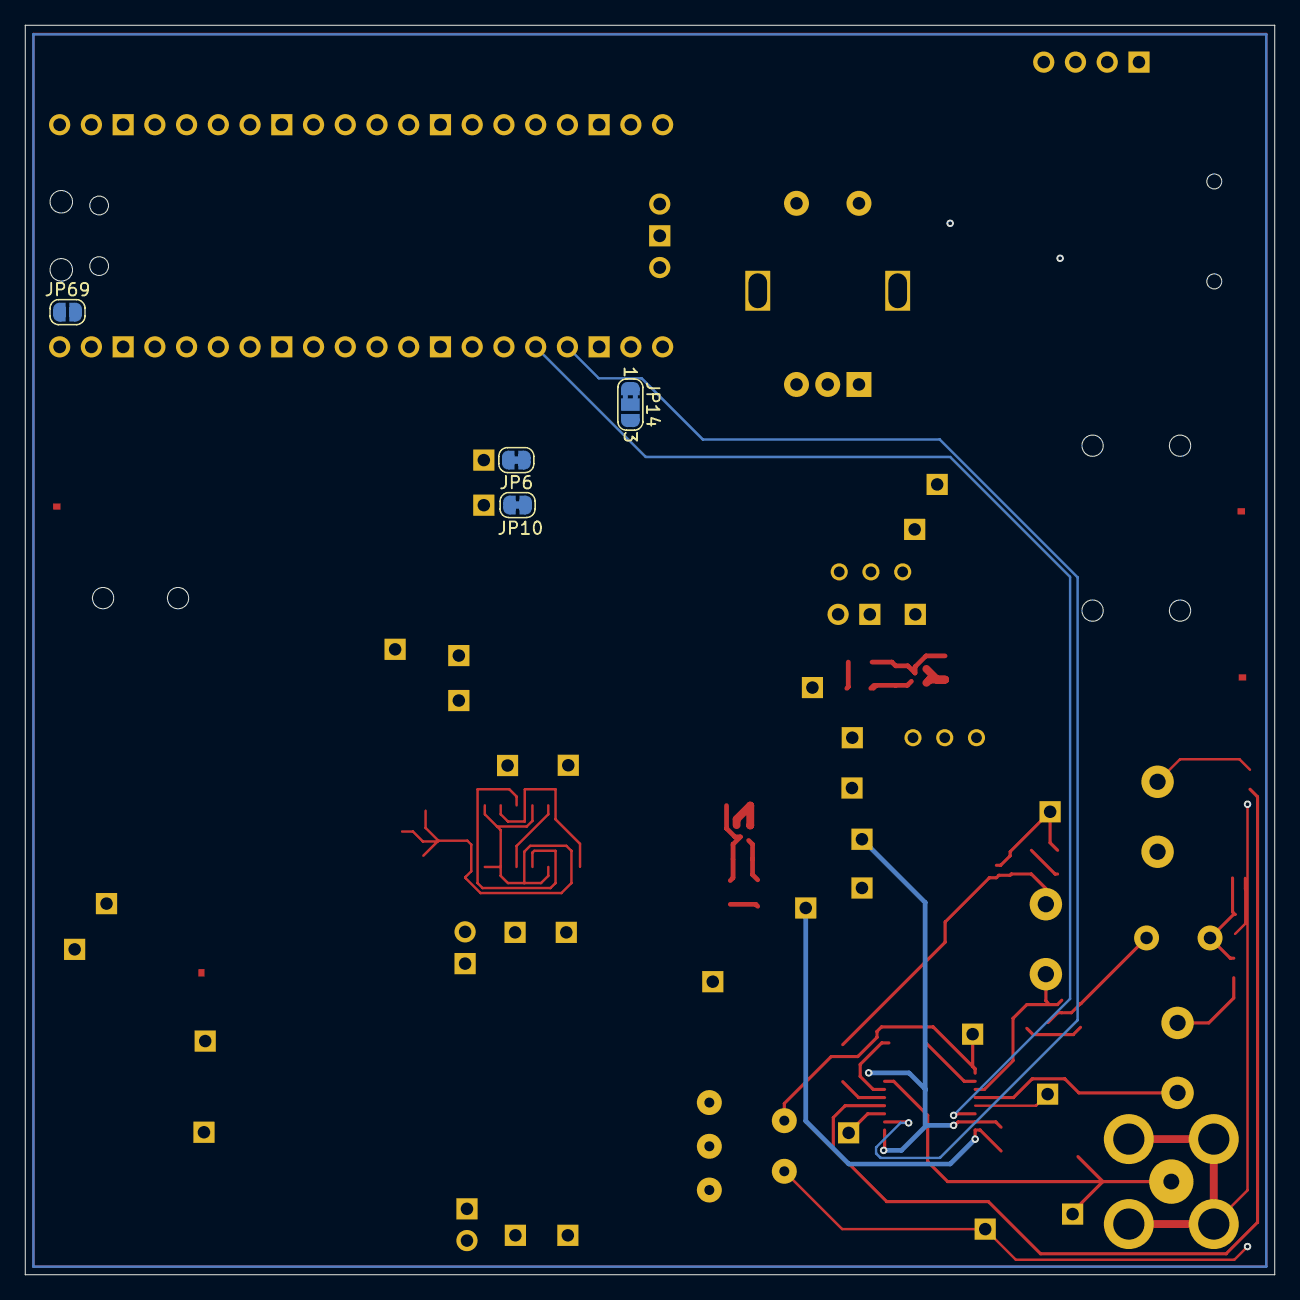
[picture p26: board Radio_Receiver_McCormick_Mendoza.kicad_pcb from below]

Board: 4 copper layers, 100.0 x 100.0 mm, 244 parts (4 on the bottom side), 136 nets.

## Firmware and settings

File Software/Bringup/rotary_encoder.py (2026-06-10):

"""
Quadrature Rotary Encoder and Button Controller
================================================
Reads a rotary encoder with detent detection and handles button inputs on RP2040.

Code structure generated with GitHub Copilot (Claude Haiku 4.5).
Modified, debugged, and hardware-tested by Jeffrey McCormick in Lab 1.

Hardware Setup:
- Rotary Encoder A:        GPIO 21
- Rotary Encoder B:        GPIO 20
- Center Click Button:     GPIO 22

All inputs use internal pull-ups (pulled HIGH, go LOW when pressed).
The script tracks rotation using quadrature encoding and prints:
- Counter value when a detent is crossed
- "Button (ring) pressed" message
- "Center click pressed" message
"""

from machine import Pin
import time


class QuadratureEncoder:
    """Handle quadrature rotary encoder with detent detection."""
    
    def __init__(self, pin_a, pin_b, ppr=1):
        """
        Initialize quadrature encoder.
        
        Args:
            pin_a: GPIO pin for encoder A signal
            pin_b: GPIO pin for encoder B signal
            ppr: Pulses per rotation/detent (default 1 for our encoder, adjust if needed)
        """
        self.pin_a = Pin(pin_a, Pin.IN, Pin.PULL_UP)
        self.pin_b = Pin(pin_b, Pin.IN, Pin.PULL_UP)
        self.counter = 0
        self.last_a = self.pin_a.value()
        self.last_b = self.pin_b.value()
        self.step_count = 0
        self.ppr = ppr
        
        # Attach interrupt handlers for edge detection on both pins
        self.pin_a.irq(trigger=Pin.IRQ_RISING | Pin.IRQ_FALLING, handler=self.on_change)
        self.pin_b.irq(trigger=Pin.IRQ_RISING | Pin.IRQ_FALLING, handler=self.on_change)
    
    def on_change(self, pin):
        """Handle changes on either encoder pin using quadrature logic."""
        current_a = self.pin_a.value()
        current_b = self.pin_b.value()
        
        # Only process on A pin changes for cleaner detent detection
        if current_a != self.last_a:
            # A changed: if B != A, we're going clockwise (increment)
            # if B == A, we're going counterclockwise (decrement)
            if current_b != current_a:
                self.step_count += 1
            else:
                self.step_count -= 1
            
            # Check if a detent has been crossed (complete quadrature cycle)
            if abs(self.step_count) >= self.ppr:
                complete_detents = int(self.step_count / self.ppr)
                self.counter += complete_detents
                self.step_count -= complete_detents * self.ppr
                direction = "CW" if complete_detents > 0 else "CCW"
                print(f"Detent crossed ({direction}) - Counter: {self.counter}")
        
        self.last_a = current_a
        self.last_b = current_b


class ButtonHandler:
    """Handle push button inputs with debouncing and long-press detection."""
    
    def __init__(self, pin, name, debounce_ms=20, long_press_ms=600, callback=None):
        """
        Initialize button handler.
        
        Args:
            pin: GPIO pin number
            name: Display name for button
            debounce_ms: Debounce time in milliseconds
            long_press_ms: Duration for long-press detection
            callback: Optional function to call on press
        """
        self.pin = Pin(pin, Pin.IN, Pin.PULL_UP)
        self.name = name
        self.debounce_ms = debounce_ms
        self.long_press_ms = long_press_ms
        self.last_press_time = 0
        self.callback = callback
        self._down = False
        self._down_at = 0
        self._long_sent = False
        self._click_pending = False
        self._long_pending = False
        
        # Attach interrupt for falling edge (button press, active LOW)
        self.pin.irq(trigger=Pin.IRQ_FALLING, handler=self.on_press)
    
    def on_press(self, pin):
        """Handle button press with debouncing."""
        current_time = time.ticks_ms()
        
        # Debounce: ignore if pressed too soon after last press
        if time.ticks_diff(current_time, self.last_press_time) < self.debounce_ms:
            return
        
        # Confirm button is still pressed (active LOW)
        if self.pin.value() == 0:
            self.last_press_time = current_time
            self._down = True
            self._down_at = current_time
            self._long_sent = False
            print(f"{self.name} pressed")
            if self.callback:
                self.callback()

    def update(self):
        """Poll button state each main loop iteration for release and long-press."""
        if not self._down:
            return

        now = time.ticks_ms()

        if self.pin.value() == 1:
            held = time.ticks_diff(now, self._down_at)
            if not self._long_sent and held < self.long_press_ms:
                self._click_pending = True
            self._down = False
            self._long_sent = False
            return

        if not self._long_sent and time.ticks_diff(now, self._down_at) >= self.long_press_ms:
            self._long_pending = True
            self._long_sent = True
            print(f"{self.name} long press")

    def get_events(self):
        """Return (short_click, long_press) since last check and clear flags."""
        clicked = self._click_pending
        long_press = self._long_pending
        self._click_pending = False
        self._long_pending = False
        return clicked, long_press
                
    def get_click(self):
        """Return True if button was clicked since last check, and clear flag."""
        clicked, _ = self.get_events()
        return clicked


if __name__ == "__main__":

    # Initialize encoder and buttons
    encoder = QuadratureEncoder(pin_a=21, pin_b=20, ppr=1)
    center_button = ButtonHandler(pin=22, name="Center click")

    print("=" * 50)
    print("Rotary Encoder and Button Controller")
    print("=" * 50)
    print("Encoder:     GPIO 21 (A) and GPIO 20 (B)")
    print("Center Button: GPIO 22")
    print("-" * 50)
    print("Turn the encoder or press buttons...\n")

    # Keep the script running
    try:
        while True:
            time.sleep(0.1)
    except KeyboardInterrupt:
        print("\nProgram stopped")

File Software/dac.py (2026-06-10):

"""
DAC code
"""
from machine import I2S, Pin
import time


class DAC:
    def __init__(
        self,
        bck_pin=15,
        ws_pin=16,
        data_pin=14,
        mute_pin=6,
        mclk_pin=17,
        i2s_id=0,
        sample_rate=44100,
        bits=16,
        buffer_size=40000,
        nonblocking=True,
    ):
        """
        Initializes the I2S interface for the PCM5102A.
        """
        self.bck_pin = bck_pin
        self.ws_pin = ws_pin
        self.data_pin = data_pin
        self.mclk_pin = mclk_pin
        self.i2s_id = i2s_id
        self.sample_rate = sample_rate
        self.bits = bits
        self.buffer_size = buffer_size
        self.nonblocking = nonblocking
        self.i2s = None
        self._drain_handler = None

        self.mclk = None
        if self.mclk_pin is not None:
            from machine import PWM
            self.mclk = PWM(Pin(self.mclk_pin))
            self.mclk.freq(self.sample_rate * 256)
            self.mclk.duty_u16(32768)

        self.mute_control = None
        if mute_pin is not None:
            self.mute_control = Pin(mute_pin, Pin.OUT)
            self.mute()

        self.set_stereo()

    def set_drain_handler(self, handler):
        """handler() is called when the I2S ring has space for more audio."""
        self._drain_handler = handler

    def _on_i2s_irq(self, i2s):
        if self._drain_handler:
            self._drain_handler()

    def mute(self):
        """Pulls the XSMT pin LOW to soft-mute the DAC output."""
        if self.mute_control:
            self.mute_control.value(0)

    def unmute(self):
        """Pulls the XSMT pin HIGH to unmute the DAC output."""
        if self.mute_control:
            self.mute_control.value(1)

    def _configure_i2s(self, format_mode):
        """Internal helper to set up or re-initialize the I2S hardware."""
        if self.i2s:
            self.i2s.deinit()

        self.i2s = I2S(
            self.i2s_id,
            sck=Pin(self.bck_pin),
            ws=Pin(self.ws_pin),
            sd=Pin(self.data_pin),
            mode=I2S.TX,
            bits=self.bits,
            format=format_mode,
            rate=self.sample_rate,
            ibuf=self.buffer_size,
        )

        if self.nonblocking:
            self.i2s.irq(self._on_i2s_irq)
        else:
            self.i2s.irq(None)

    def set_mono(self):
        """Configures the I2S stream for Mono (Pico duplicates L/R internally)."""
        self._configure_i2s(I2S.MONO)
        print(f"PCM5102A configured for Dual-Mono at {self.sample_rate}Hz")

    def set_stereo(self):
        """Configures the I2S stream for true Stereo output."""
        self._configure_i2s(I2S.STEREO)
        mode = "non-blocking" if self.nonblocking else "blocking"
        print(f"PCM5102A configured for Stereo at {self.sample_rate}Hz ({mode})")

    def write(self, audio_buffer, length=None):
        """
        Write audio to I2S.
        Non-blocking: returns bytes accepted immediately (may be partial).
        Blocking: loops until the full chunk is queued.
        """
        if not self.i2s:
            return 0

        view = memoryview(audio_buffer)
        if length is not None:
            view = view[:length]

        if self.nonblocking:
            return self.i2s.write(view)

        offset = 0
        total = len(view)
        while offset < total:
            offset += self.i2s.write(view[offset:])
        return offset

    def write_buffer(self, audio_buffer, length=None):
        """Alias for write(); kept for older callers."""
        return self.write(audio_buffer, length)

    def close(self):
        """Mutes the DAC and safely shuts down the I2S peripheral."""
        self._drain_handler = None
        if self.i2s:
            self.i2s.irq(None)
        self.mute()
        time.sleep_ms(20)
        if self.i2s:
            self.i2s.deinit()


if __name__ == "__main__":
    import struct
    import math

    dac = DAC(nonblocking=False)
    dac.unmute()

    sample_rate = 44100
    freq = 440
    num_samples = sample_rate
    buf = bytearray(num_samples * 4)

    for i in range(num_samples):
        val = int(32767 * math.sin(2 * math.pi * freq * i / sample_rate))
        struct.pack_into("<hh", buf, i * 4, val, val)

    dac.write_buffer(buf)

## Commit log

2026-04-20 Added KiCAD files and References to parts and design resources.
    [Display.kicad_sch, RP-2040.kicad_sch, Radio_Receiver_McCormick_Mendoza.kicad_pcb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]
2026-04-20 Added KiCAD files and references to part resources
    [Display.kicad_sch, RP-2040.kicad_sch, Radio_Receiver_McCormick_Mendoza.kicad_pcb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]
2026-04-20 slight updates to the KiCad files
    [Radio_Receiver_McCormick_Mendoza.kicad_sch, clock_generator.kicad_sch]
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2026-04-21 Propogated Title Block Fields
    [Display.kicad_sch, RP-2040.kicad_sch, antenna.kicad_sch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]
2026-04-21 Added basic antenna and bandpass filter schematic.
    [antenna.kicad_sch, power_supply.kicad_sch]
2026-04-21 Added Tayloe Detector MUX symbol and footprint
    [mixer.kicad_sch]
2026-04-22 Added Bibliography entry
    [Radio_Receiver_McCormick_Mendoza.kicad_sch, antenna.kicad_sch, power_supply.kicad_sch]
2026-04-24 Added Daniel Mendoza's changes to KiCAD files.
    [clock_generator.kicad_sch, low_pass_filter.kicad_sch, mixer.kicad_sch]
2026-04-29 Added switchable antenna filters and photos.
    [ADC-24bit.kicad_sch, RP-2040.kicad_sch, Radio_Receiver_McCormick_Mendoza.kicad_sch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]
2026-04-29 Added footprints
    [clock_generator.kicad_sch, low_pass_filter.kicad_sch]
2026-04-29 Schematic connection edits
    [ADC-24bit.kicad_sch, RP-2040.kicad_sch, antenna.kicad_sch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]
2026-04-30 Schematic edits power and signal systems
    [ADC-24bit.kicad_sch, Display.kicad_sch, Radio_Receiver_McCormick_Mendoza.kicad_sch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]
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2026-04-30 Added bibliography source and schematic edits
    [ADC-24bit.kicad_sch, raspberry_pi_pico.kicad_sch]
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2026-05-01 Added reference voltage stability by buffer amp
    [ADC-24bit.kicad_sch, Radio_Receiver_McCormick_Mendoza.kicad_sch, antenna.kicad_sch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]
2026-05-01 Isolated filter switching MUX from digital control
    [ADC-24bit.kicad_sch, Radio_Receiver_McCormick_Mendoza.kicad_sch, antenna.kicad_sch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]
2026-05-02 Added DAC and shaft angle encoder
    [ADC-24bit.kicad_sch, Angle_Encoder.kicad_sch, Audio_DAC.kicad_sch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]
2026-05-04 Added digital power regulator
    [ADC-24bit.kicad_sch, Angle_Encoder.kicad_sch, Audio_DAC.kicad_sch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]
2026-05-05 Integrated signal path modules
    [ADC-24bit.kicad_sch, Angle_Encoder.kicad_sch, Audio_DAC.kicad_sch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]
2026-05-05 Adjusted RF filters for basic component values
    [antenna.kicad_sch]
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2026-05-05 Finalized Pico connections and added indicator LEDs
    [ADC-24bit.kicad_sch, Audio_DAC.kicad_sch, Radio_Receiver_McCormick_Mendoza.kicad_sch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]
2026-05-06 Added transformer footprint and datasheet
    [ADC-24bit.kicad_sch, Audio_DAC.kicad_sch, Radio_Receiver_McCormick_Mendoza.kicad_sch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]
2026-05-06 Swapped voltage regulator to output 4.5V
    [ADC-24bit.kicad_sch, Audio_DAC.kicad_sch, Radio_Receiver_McCormick_Mendoza.kicad_sch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]
2026-05-06 Corrected mono to headphones
    [ADC-24bit.kicad_sch, Audio_DAC.kicad_sch]
2026-05-06 Added the bnc connector footprint provided by dr Frohne
    [antenna.kicad_sch]
2026-05-07 Created low mono, high stereo impedance DAC audio outlets
    [ADC-24bit.kicad_sch, Audio_DAC.kicad_sch, clock_generator.kicad_sch]
2026-05-07 Added MicroSD card and verified footprints
    [ADC-24bit.kicad_sch, Audio_DAC.kicad_sch, MicroSD.kicad_sch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]
2026-05-07 Updated footprints
    [ADC-24bit.kicad_sch, Radio_Receiver_McCormick_Mendoza.kicad_pcb, clock_generator.kicad_sch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]
2026-05-07 Started PCB
    [Radio_Receiver_McCormick_Mendoza.kicad_pcb]
2026-05-07 Edited PCB Power
    [Radio_Receiver_McCormick_Mendoza.kicad_pcb]
2026-05-08 Created duplicate to work parallel without merge conflicts
    [ADC-24bit.kicad_sch, Angle_Encoder.kicad_sch, Audio_DAC.kicad_sch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]
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2026-05-08 Arranged power components on PCB
    [Radio_Receiver_McCormick_Mendoza.kicad_pcb, power_supply.kicad_sch]
2026-05-08 Fixed the clock and johnson counter
    [Radio_Receiver_McCormick_Mendoza_Duplicate.kicad_pcb]
2026-05-08 Arranged antenna and mixer components on PCB
    [Radio_Receiver_McCormick_Mendoza.kicad_pcb, antenna.kicad_sch]
2026-05-08 Added pico and OLED arrangement to PCB
    [Radio_Receiver_McCormick_Mendoza.kicad_pcb, raspberry_pi_pico.kicad_sch]
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2026-05-08 Continue on layout of PCB
    [Radio_Receiver_McCormick_Mendoza.kicad_pcb]
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2026-05-08 Added traces for mixer and fixed placing
    [ADC-24bit.kicad_sch, Angle_Encoder.kicad_sch, Audio_DAC.kicad_sch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]
2026-05-08 Placed ADC and DAC onto the PCB layout
    [Radio_Receiver_McCormick_Mendoza.kicad_pcb]
2026-05-08 Laid out all components to fit on PCB
    [Radio_Receiver_McCormick_Mendoza.kicad_pcb]
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2026-05-08 Added netclasses for all the critical trace types
    [Radio_Receiver_McCormick_Mendoza.kicad_pcb]
2026-05-08 New_Duplicate is the new copy working with traces Not everything on the right diagonal is connected
    [ADC-24bit.kicad_sch, Angle_Encoder.kicad_sch, Audio_DAC.kicad_sch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]
2026-05-10 More tracing done. Not completly finished.
    [New_Duplicate.kicad_pcb]
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2026-05-14 Routed antenna and isolated GNDA
    [ADC-24bit.kicad_sch, Audio_DAC.kicad_sch, MicroSD.kicad_sch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]
2026-05-14 Resolved non-connection related DRC errors and warnings
    [Radio_Receiver_McCormick_Mendoza.kicad_pcb]
2026-05-14 back copper tracing for raspberry pi done
    [New_Duplicate.kicad_pcb]
2026-05-15 Finished routing master copy and added GND and PWR planes with vias
    [ADC-24bit.kicad_sch, Audio_DAC.kicad_sch, clock_generator.kicad_sch]
2026-05-15 Corrected footprints saved to Reciever_Parts.pretty
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2026-05-16 Corrected stereo and mono audio jacks' footprints
    [Audio_DAC.kicad_sch]
2026-06-03 Added Turn and Core type values to the hand-wound inductors and transformer
    [antenna.kicad_sch]
2026-06-05 Added Micropython files for board bring-up testing
    [antenna.kicad_sch]
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2026-06-10 something might be fixed
    [sd.py, sdcard.py]
2026-06-10 cleanup ladies and gents
    [ADC-24bit.kicad_sch, Angle_Encoder.kicad_sch, Audio_DAC.kicad_sch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]
